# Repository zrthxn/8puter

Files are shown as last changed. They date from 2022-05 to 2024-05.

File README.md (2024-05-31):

# 8puter

This is a Homebrew 8-bit computer project, using mostly simple modern parts.
Based on the legendary MOS6502 processor, we are using the modern CMOS version made by WDC. Basically an exercise in computer architechture. I plan to get this manufactured into a PCB and assemble myself into a working computer. 

Please feel free to leave reviews/sanity checks from people who have done this sort of thing before, or know something about this, in the [issues](/issues).  

## Preview

Here is a picture of a 3D model of the completed PCB.
<p align="center">
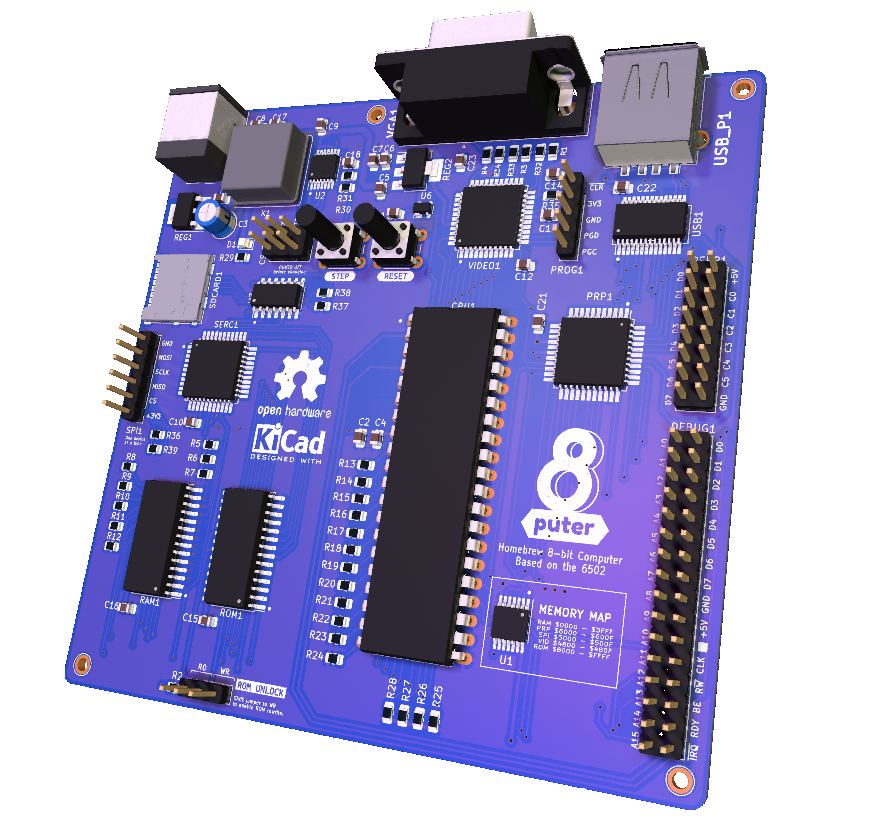
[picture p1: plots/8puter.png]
  
</p>

<p align="center" style="text-align: center; font-size: larger; font-weight: 600;">
// 
<a href="plots/8puter.pdf">Schematic</a> / 
<a href="plots/8puter.csv">Bill of Materials</a> 
//
</p>

## My Goals

The main thing I want to be able to do with this SBC is to program it with itself. This means having some way to input text from a keyboard and display it to some kind of screen/output device, and I've chosen a VGA monitor for this. I'm not trying to keep this compatible with the ROMs/BIOSs or code of old but I want to be able to write my own, preferably on the machine itself. 
Also, I dont want to use discrete logic for everything since I have some experience with trying to make that work. I'm also not necessarily using all DIP chips because of lack space, and going SMD isnt that much of a problem.

To store programs on a sort of "disk", I thought I need to add some sort of serial interface which can talk to a microSD card, such that the computer can use it as storage. This is accomplished via SPI. 
The peripheral interface talks to a USB controller and *should* be able to use a USB keyboard as input device. This idea was taken from the schematic of the [SBC dev board that WDC sells](https://wdc65xx.com/Single-Board-Computers/w65c02sxb/).

The video signal is being generated by a microcontroller because I thought that's probably the easiest way to get it working without worrying about a lot of VGA signal timing. This MCU is fast enough to generate a 640x480 screen and has enough memory to store the framebuffer and its the only *cheat* I've used. Some more details are in my schematic

### Main Parts

**uProcessor:** W65C02S  
**ROM and RAM:** AT28C256 and AS6C62256, both 32K  
**VIA:** W65C22  
**USB I/f:** FT245RL  
**Video:** PIC32MX270 uController

## Manufacturing

So after quite a while, I have finally got this PCB manufactured and it came out better than I had imagined.
I was having trouble finding a local PCB maker who had the right capabilities and would manufacture this board at a small scale. 
Then I found Robu.in and their manufacturing service. I'm not sure if they've been doing this for a while but I never knew about them.

The board files are ready to send to a manufacturer of your choice as they are. You can find the gerbers in a ZIP and just fire them off. 
I recommend Robu.in if you're in India. Otherwise I'd recommend PCBWay.com



See the [Releases](https://github.com/zrthxn/8puter/releases) for updates.

## Resources

Some great resources I found for this project, including those from people who have done this sort of thing before.

- [Ben Eater's Excellent Videos](https://www.youtube.com/watch?v=LnzuMJLZRdU&list=PLowKtXNTBypFbtuVMUVXNR0z1mu7dp7eH)
- [George Foot's videos](https://www.youtube.com/watch?v=EC1Ous1zT5w&list=PLWKtKD_FaUF6IsFc1maERpOwWM2hrOM3b)
- [forum.6502.org](http://forum.6502.org/)
- [WDC's own SBC board schematic](https://wdc65xx.com/Single-Board-Computers/w65c02sxb/)
- [6052 Primer](http://wilsonminesco.com/6502primer) on how to get started building your own, especially the [address decode](http://wilsonminesco.com/6502primer/addr_decoding.html) section
- [6502.org: Homebuilt Projects](http://www.6502.org/homebuilt)
- [This guy's breadboard computer](https://www.youtube.com/watch?v=sdFXc0Rkpvc&list=PLdGm_pyUmoII9D16mzw-XsJjHKi3f1kqT) which is based on the (later) 65816 processor, but has some great ideas.

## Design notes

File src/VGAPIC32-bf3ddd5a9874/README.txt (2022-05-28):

Introduction
------------

The VGAPIC32 project provides software and circuit information to generate an
analogue VGA signal from a PIC32 microcontroller. More details can be found in
the following article:

http://blogs.fsfe.org/pboddie/?p=1712

See also the docs directory for original versions of the different explanatory
diagrams.

Contact, Copyright and Licence Information
------------------------------------------

The author can be contacted at the following e-mail address:

paul@boddie.org.uk

Copyright and licence information can be found in the docs directory - see
docs/COPYING.txt and docs/gpl-3.0.txt for more information.

Hardware Details
================

The pin usage of this solution is documented below.

PIC32MX270F256B-50I/SP Pin Assignments
--------------------------------------

MCLR#          1  \/  28
HSYNC/OC1/RA0  2      27
VSYNC/OC2/RA1  3      26 RB15
       D0/RB0  4      25 RB14
       D1/RB1  5      24 RB13
       D2/RB2  6      23
       D3/RB3  7      22 RB11/PGEC2
               8      21 RB10/PGEC3
          RA2  9      20
          RA3 10      19
       D4/RB4 11      18 RB9
              12      17 RB8
              13      16 RB7/D7
       D5/RB5 14      15

Note that RB6 is not available on pin 15 on this device.

Data Signal Routing
-------------------

For one bit of intensity, two bits per colour channel:

D7 -> 2200R -> I

I -> diode -> R
I -> diode -> G
I -> diode -> B

D6 (not connected)

D5 -> 470R -> R
D4 -> 1000R -> R
D3 -> 470R -> G
D2 -> 1000R -> G
D1 -> 470R -> B
D0 -> 1000R -> B

HSYNC -> HS
VSYNC -> VS

Output Socket Pinout
--------------------

  5 (GND)  4 (NC)   3 (B)    2 (G)    1 (R)

      10 (GND) 9 (NC)   8 (GND)  7 (GND)  6 (GND)

  15 (NC)  14 (VS)  13 (HS)  12 (NC)  11 (NC)

Output Cable Pinout
-------------------

      1 (R)    2 (G)    3 (B)    4 (NC)   5 (GND)

  6 (GND)  7 (GND)  8 (GND)  9 (NC)   10 (GND)

      11 (NC)  12 (NC)  13 (HS)  14 (VS)  15 (NC)

References
----------

https://en.wikipedia.org/wiki/VGA_connector

http://papilio.cc/index.php?n=Papilio.VGAWing

http://lucidscience.com/pro-vga%20video%20generator-2.aspx

https://sites.google.com/site/h2obsession/CBM/C128/rgbi-to-vga

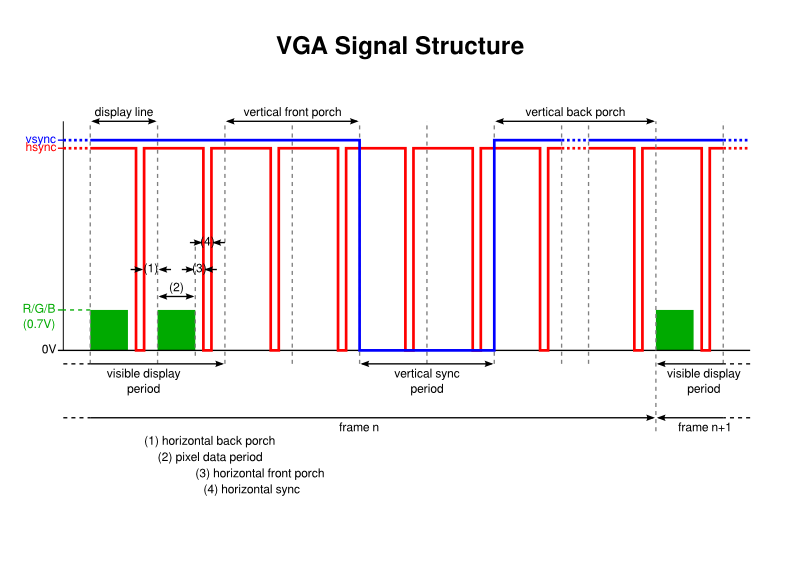
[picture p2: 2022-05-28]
src/VGAPIC32-bf3ddd5a9874/docs/vga_timing.png

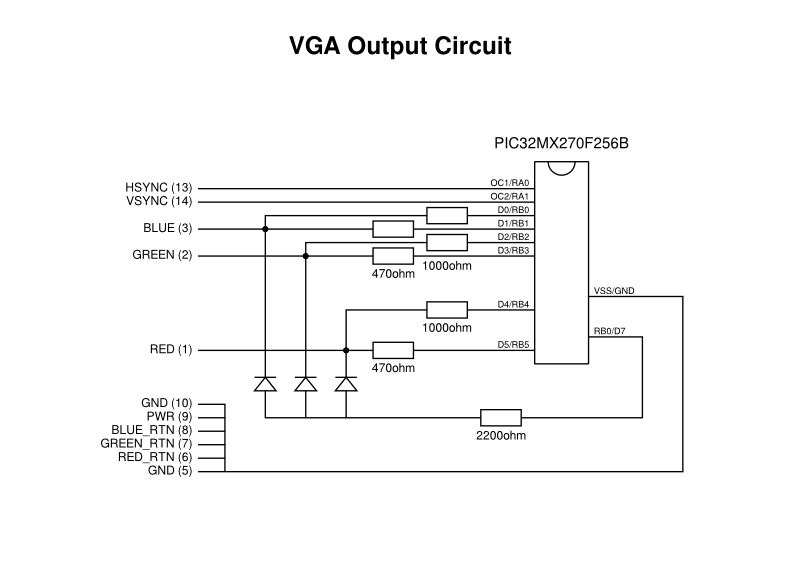
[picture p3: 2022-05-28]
src/VGAPIC32-bf3ddd5a9874/docs/vga_circuit.png

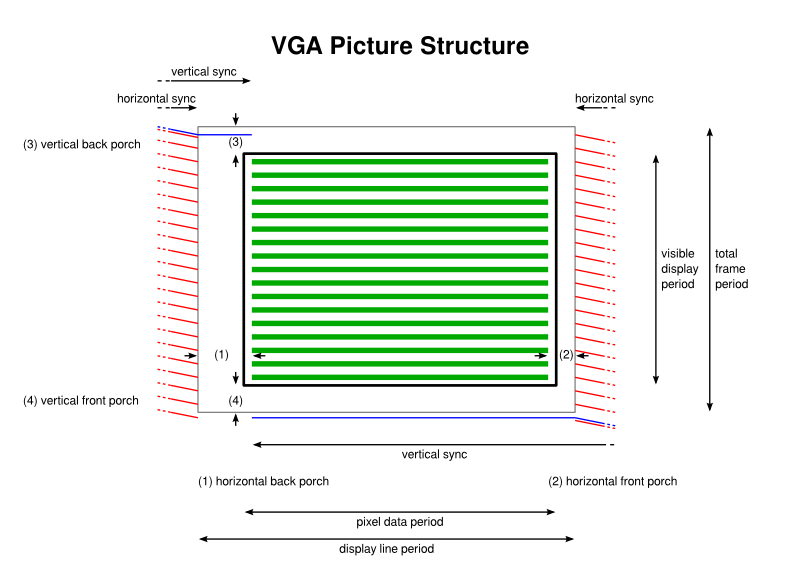
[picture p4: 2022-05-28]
src/VGAPIC32-bf3ddd5a9874/docs/vga_picture.png

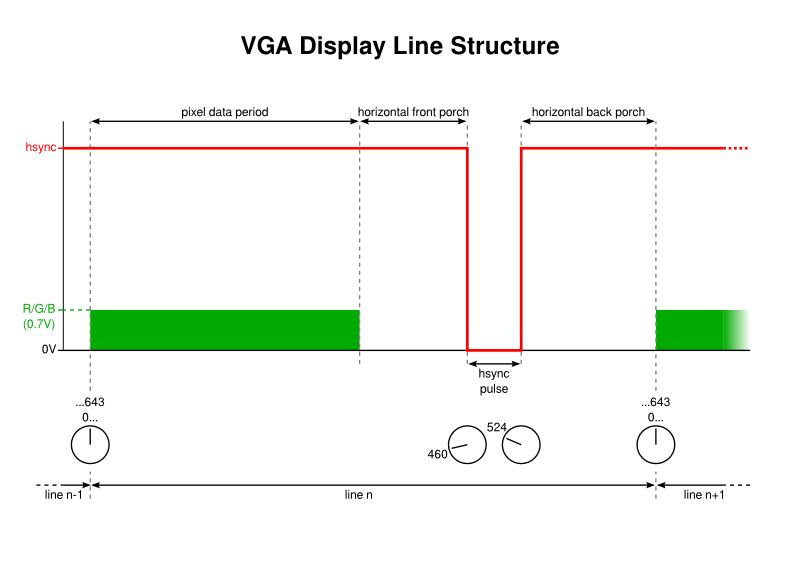
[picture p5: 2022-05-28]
src/VGAPIC32-bf3ddd5a9874/docs/vga_hsync.png

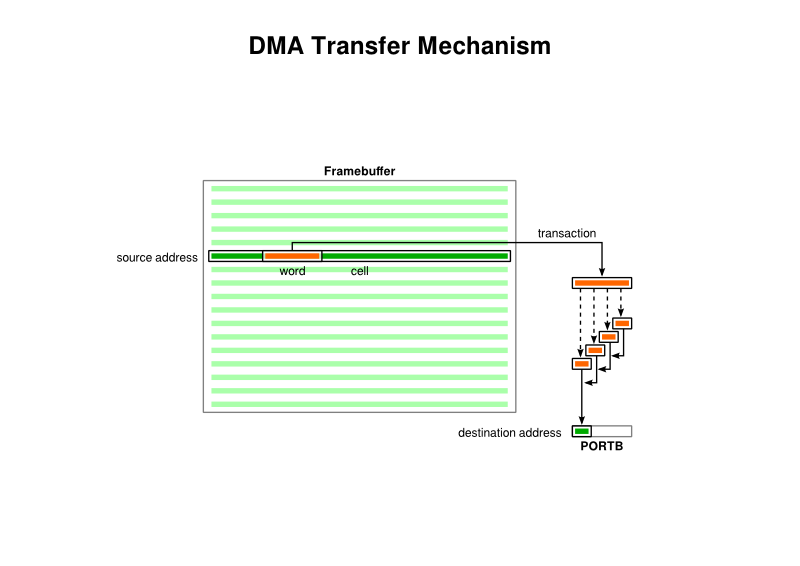
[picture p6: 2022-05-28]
src/VGAPIC32-bf3ddd5a9874/docs/dma_transfer.png

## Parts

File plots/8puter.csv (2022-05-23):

Id | Designator | Package | Quantity | Designation | Supplier and ref
1 | PERP1 | PinHeader_2x08_P2.54mm_Vertical | 1 | Conn_02x08_Odd_Even
2 | C15,C8,C9,C21,C16,C11,C22,C13,C14,C7,C10,C23 | C_0805_2012Metric | 12 | 100nF
3 | R30,R35 | R_0805_2012Metric | 2 | 10K
4 | R22,R28,R16,R13,R39,R11,R19,R2,R18,R6,R15,R4,R37,R27,R23,R24,R17,R36,R1,R9,R10,R29,R38,R25,R26,R20,R3,R14,R8,R21,R5,R7,R12 | R_0805_2012Metric | 33 | 1K
5 | SDCARD1 | microSD_HC_Molex_104031-0811 | 1 | Micro_SD_Card
6 | RESET_SW1,STEP_SW1 | SW_PUSH_6mm_H13mm | 2 | PUSHBTN
7 | ROM1 | SOIC-28W_7.5x17.9mm_P1.27mm | 1 | AT28HC256E-90SU
8 | U6 | SOT-143 | 1 | MAX811TEUS+T
9 | ROM_WRITE1 | PinHeader_1x03_P2.54mm_Vertical | 1 | Conn_01x03
10 | CPU1 | DIP-40_W15.24mm_LongPads | 1 | W65C02SxP
11 | R32,R34,R33 | R_0805_2012Metric | 3 | 470R
12 | C2,C17,C6,C18 | C_0805_2012Metric | 4 | 1uF
13 | REG2 | SOT-223-3_TabPin2 | 1 | NCP1117ST33T3G
14 | SERC1,PRP1 | PQFP-44_10x10mm_P0.8mm | 2 | W65C22SxQ
15 | PROG1 | PinHeader_1x05_P2.54mm_Vertical | 1 | Conn_01x05
16 | C3 | CP_Radial_D5.0mm_P2.50mm | 1 | 10uF 16V
17 | U1 | TSSOP-14_4.4x5mm_P0.65mm | 1 | 74AC00
18 | D1 | LED_0805_2012Metric | 1 | LED
19 | VGA1 | DSUB-15-HD_Female_Horizontal_P2.29x1.98mm_EdgePinOffset3.03mm_Housed_MountingHolesOffset4.94mm | 1 | DB15_Female_HighDensity
20 | SPI1 | PinHeader_1x06_P2.54mm_Vertical | 1 | Conn_01x06
21 | C4,C12,C1,C5 | C_0805_2012Metric | 4 | 10uF
22 | DEBUG1 | PinHeader_2x16_P2.54mm_Vertical | 1 | Conn_02x16_Odd_Even
23 | U3 | SOIC-14_3.9x8.7mm_P1.27mm | 1 | 74HC126
24 | USB1 | SSOP-28_5.3x10.2mm_P0.65mm | 1 | FT245RL
25 | RAM1 | SOIC-28W_7.5x17.9mm_P1.27mm | 1 | AS6C62256-55SINTR
26 | VIDEO1 | TQFP-44_10x10mm_P0.8mm | 1 | PIC32MX270F256D
27 | J1 | BarrelJack_CUI_PJ-063AH_Horizontal | 1 | PWR-DC
28 | REG1 | SOT-223-3_TabPin2 | 1 | NCP1117ST50T3G
29 | CS_SEL1 | PinHeader_2x03_P2.54mm_Vertical | 1 | Conn_02x03_Odd_Even
30 | U2 | TSSOP-14_4.4x5mm_P0.65mm | 1 | 74AHC74
31 | R31 | R_0805_2012Metric | 1 | 47K
32 | USB_P1 | USB_A_TE_292303-7_Horizontal | 1 | USB_A
33 | X1 | Oscillator_DIP-8 | 1 | ECS-2200BX-100

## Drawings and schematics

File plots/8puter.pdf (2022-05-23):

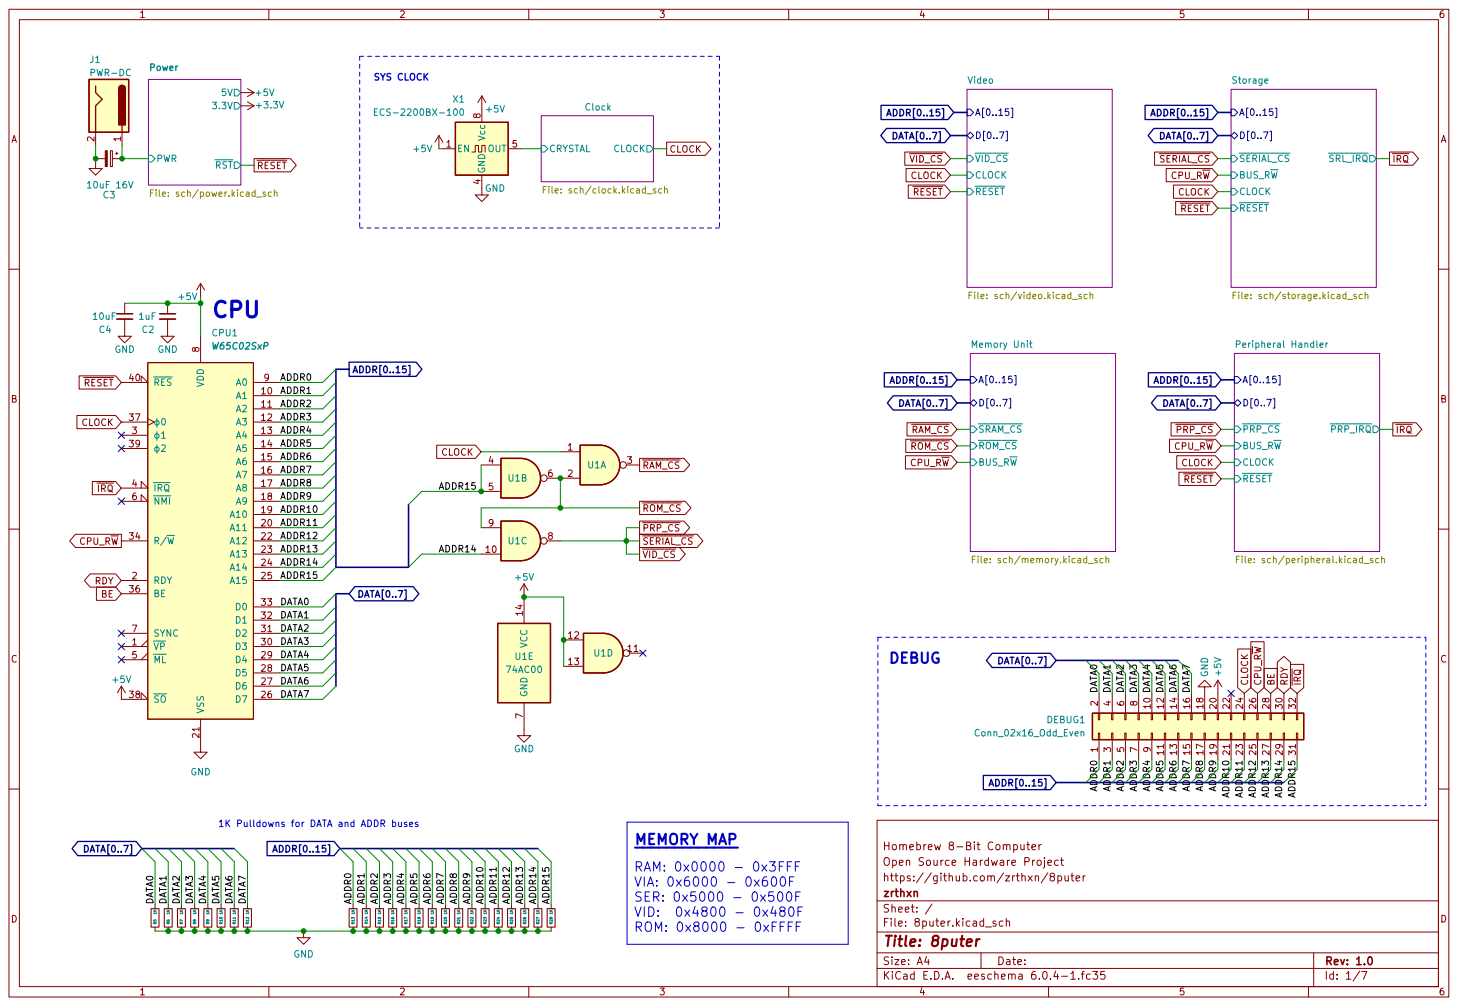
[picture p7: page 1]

+5V GND R17 1K +5V
File: sch/peripheral.kicad_sch PWR
1K Pulldowns for DATA and ADDR buses CPU

A[0..15] Video File: sch/video.kicad_sch A[0..15]
~{VID_CS} CLOCK DATA[0..7]

File: sch/storage.kicad_sch GNDVCC 14 GND

Homebrew 8-Bit Computer
Open Source Hardware Project
https://github.com/zrthxn/8puter
File: 8puter.kicad_sch Sheet: / zrthxn

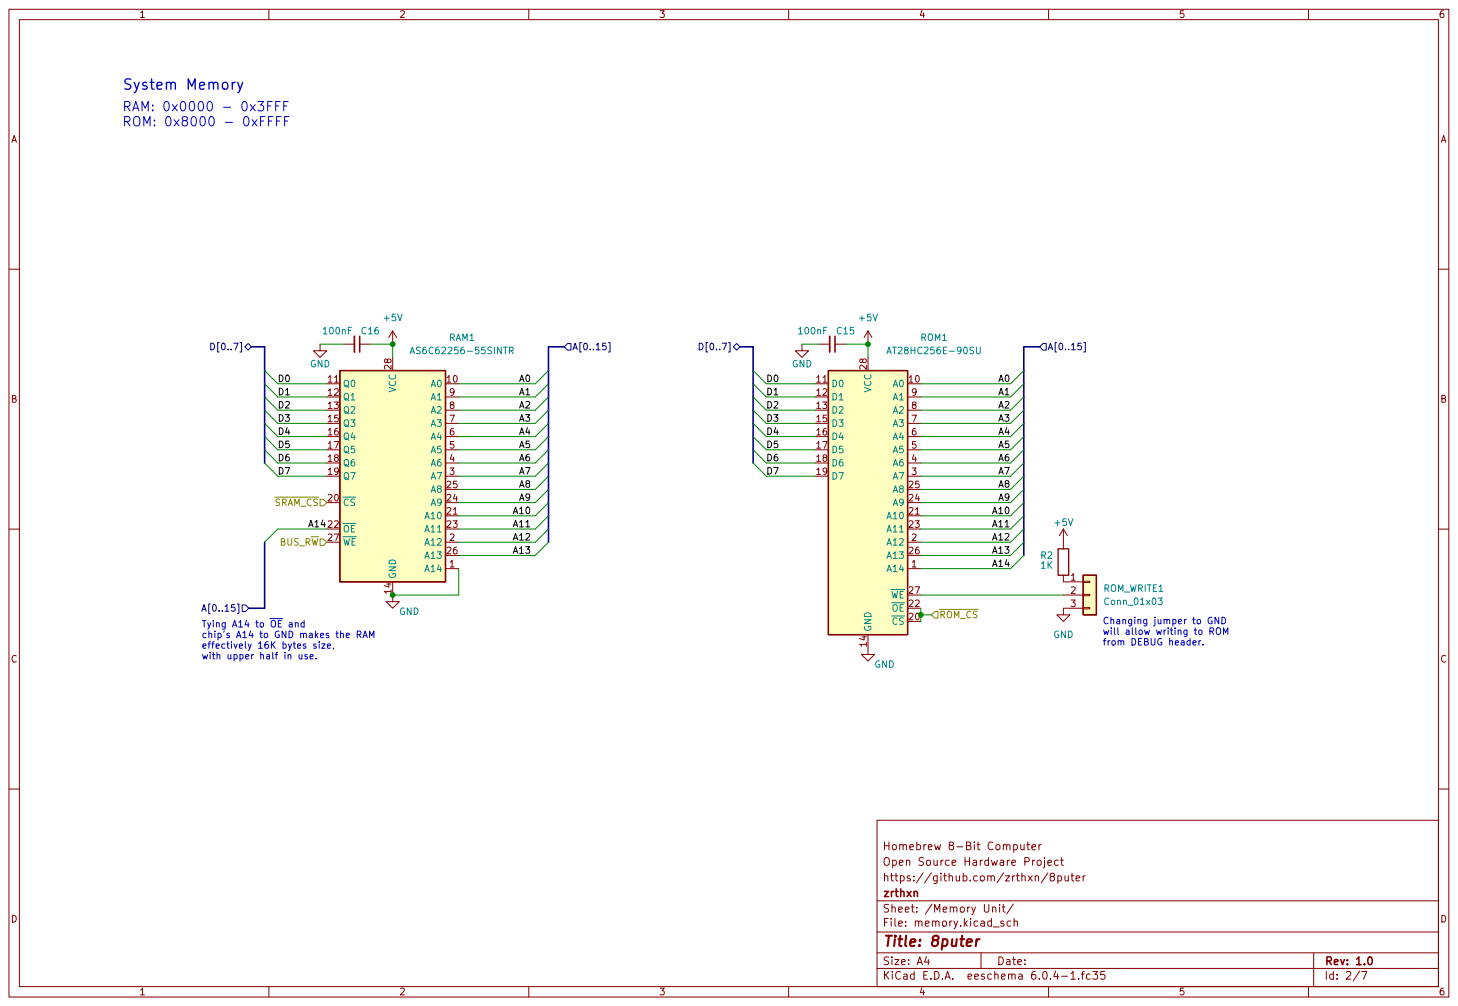
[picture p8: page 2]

Changing jumper to GND
will allow writing to ROM
from DEBUG header.

chip's A14 to GND makes the RAM
effectively 16K bytes size,
with upper half in use.

Homebrew 8-Bit Computer
Open Source Hardware Project
https://github.com/zrthxn/8puter
Sheet: /Memory Unit/ zrthxn

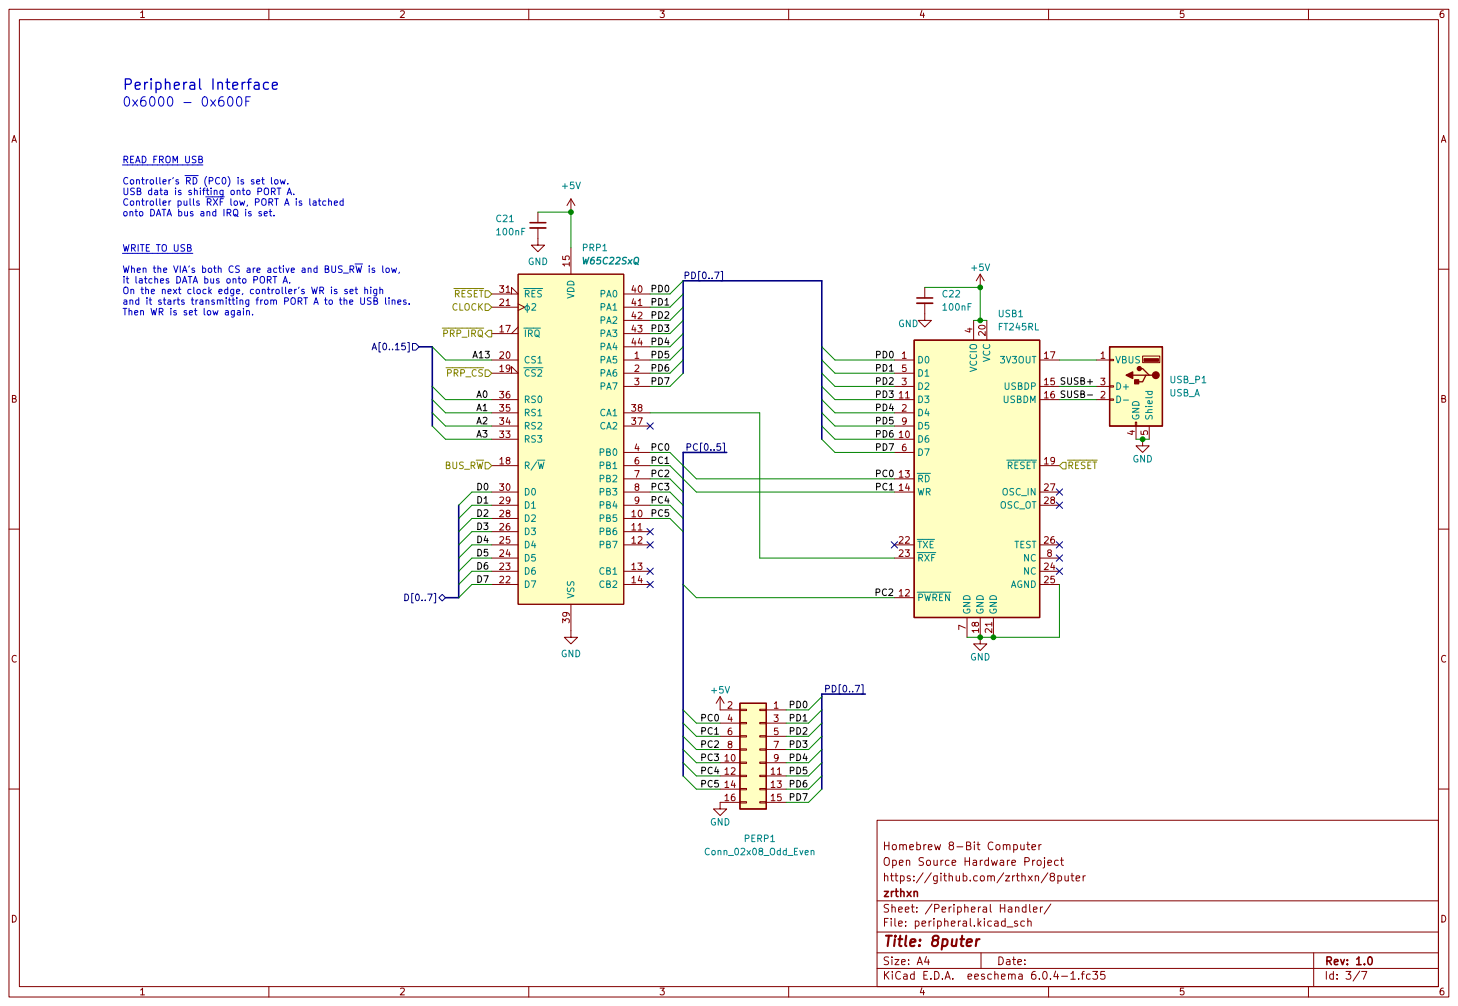
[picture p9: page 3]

Peripheral Interface WRITE TO USB
onto DATA bus and IRQ is set. 0x6000 - 0x600F

Controller's ~{RD} (PC0) is set low.
USB data is shifting onto PORT A.
Controller pulls ~{RXF} low, PORT A is latched

When the VIA's both CS are active and BUS_R~{W} is low,
it latches DATA bus onto PORT A. On the next clock edge, controller's WR is set high

and it starts transmitting from PORT A to the USB lines.
Then WR is set low again.

Homebrew 8-Bit Computer
Open Source Hardware Project
https://github.com/zrthxn/8puter
Sheet: /Peripheral Handler/ zrthxn

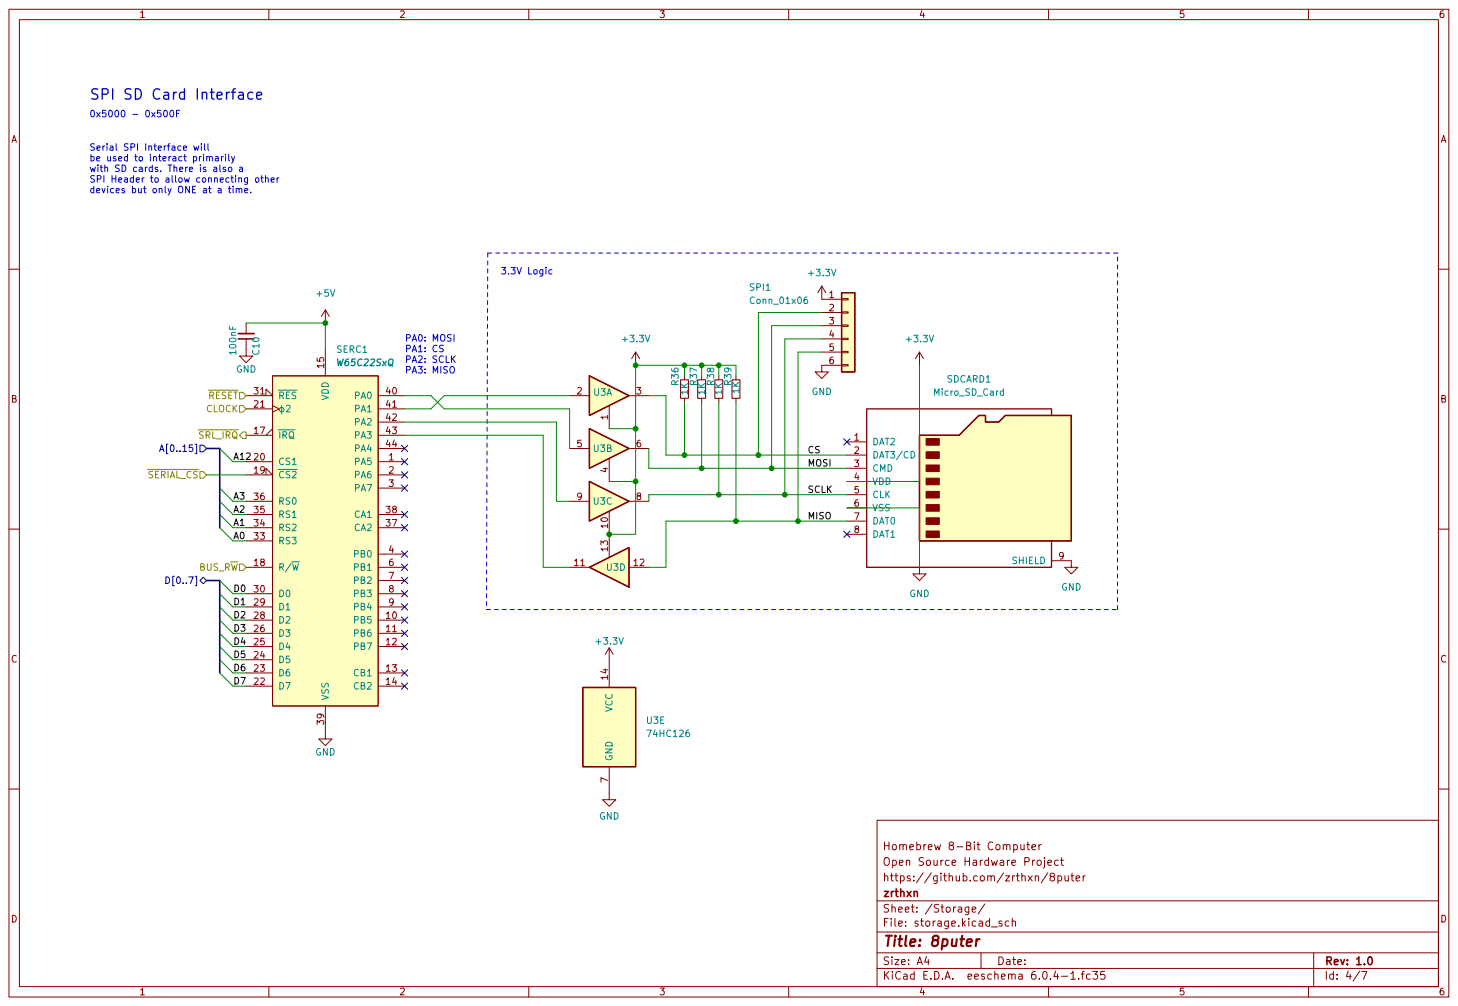
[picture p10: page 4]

SPI SD Card Interface

0x5000 - 0x500F Serial SPI Interface will be used to interact primarily with SD cards. There is also a SPI Header to allow connecting other

devices but only ONE at a time.

Open Source Hardware Project
https://github.com/zrthxn/8puter
Sheet: /Storage/ zrthxn

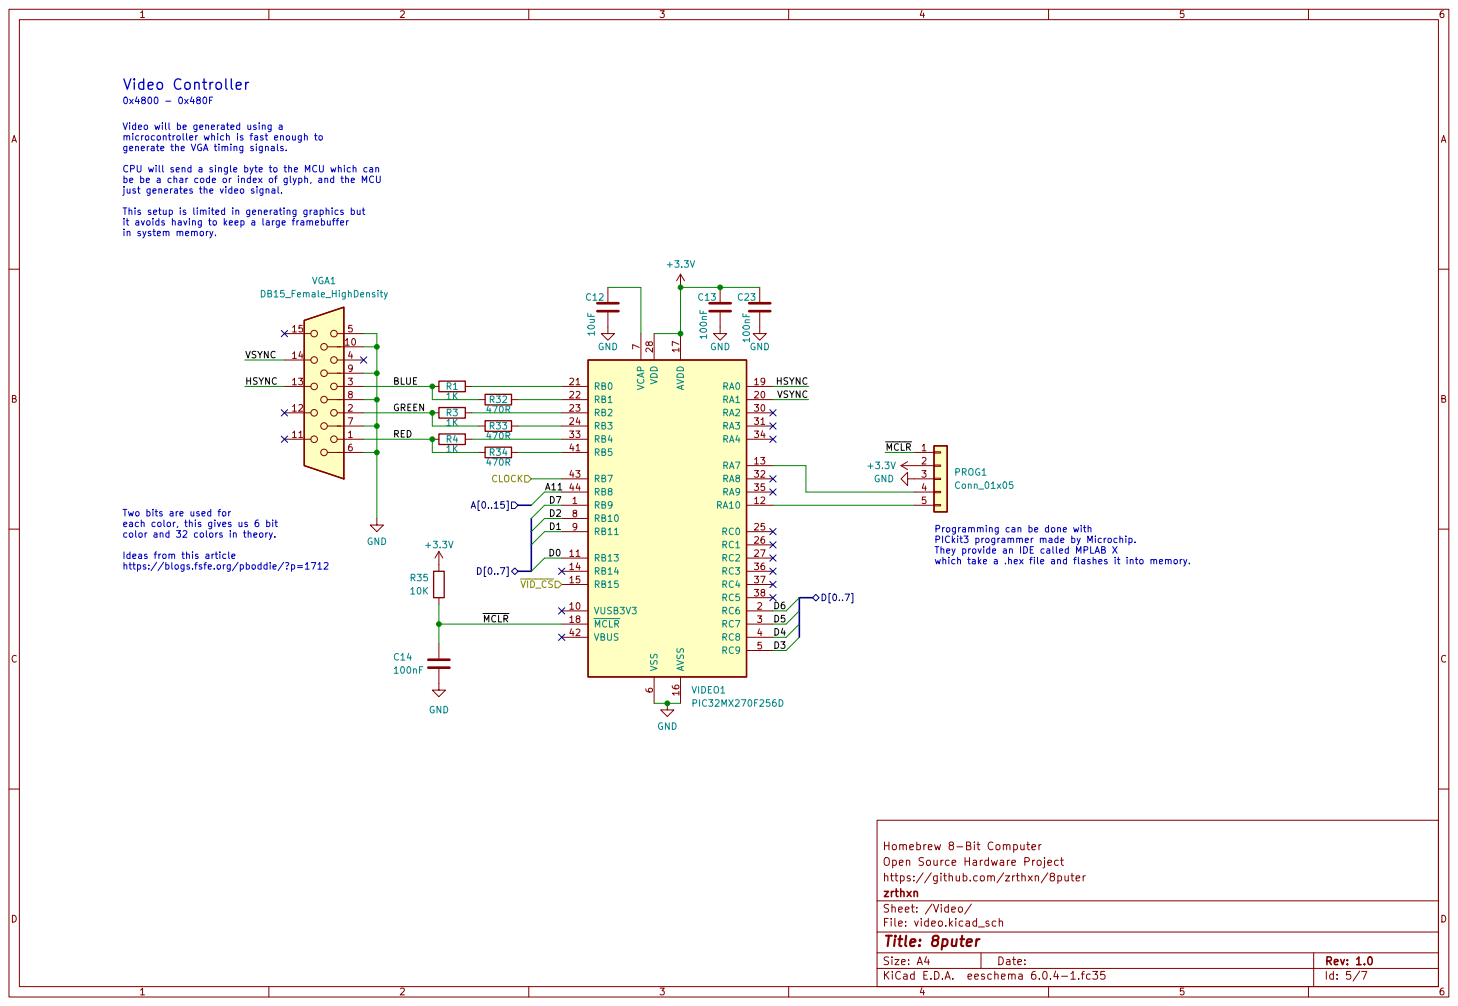
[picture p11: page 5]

Video Controller
0x4800 - 0x480F Video will be generated using a

microcontroller which is fast enough to
generate the VGA timing signals.

CPU will send a single byte to the MCU which can
be be a char code or index of glyph, and the MCU
just generates the video signal.

This setup is limited in generating graphics but
it avoids having to keep a large framebuffer
in system memory.

color and 32 colors in theory.

Programming can be done with
PICkit3 programmer made by Microchip.
They provide an IDE called MPLAB X
which take a .hex file and flashes it into memory.

Ideas from this article
https://blogs.fsfe.org/pboddie/?p=1712

Homebrew 8-Bit Computer
Open Source Hardware Project
https://github.com/zrthxn/8puter
File: video.kicad_sch Sheet: /Video/ zrthxn

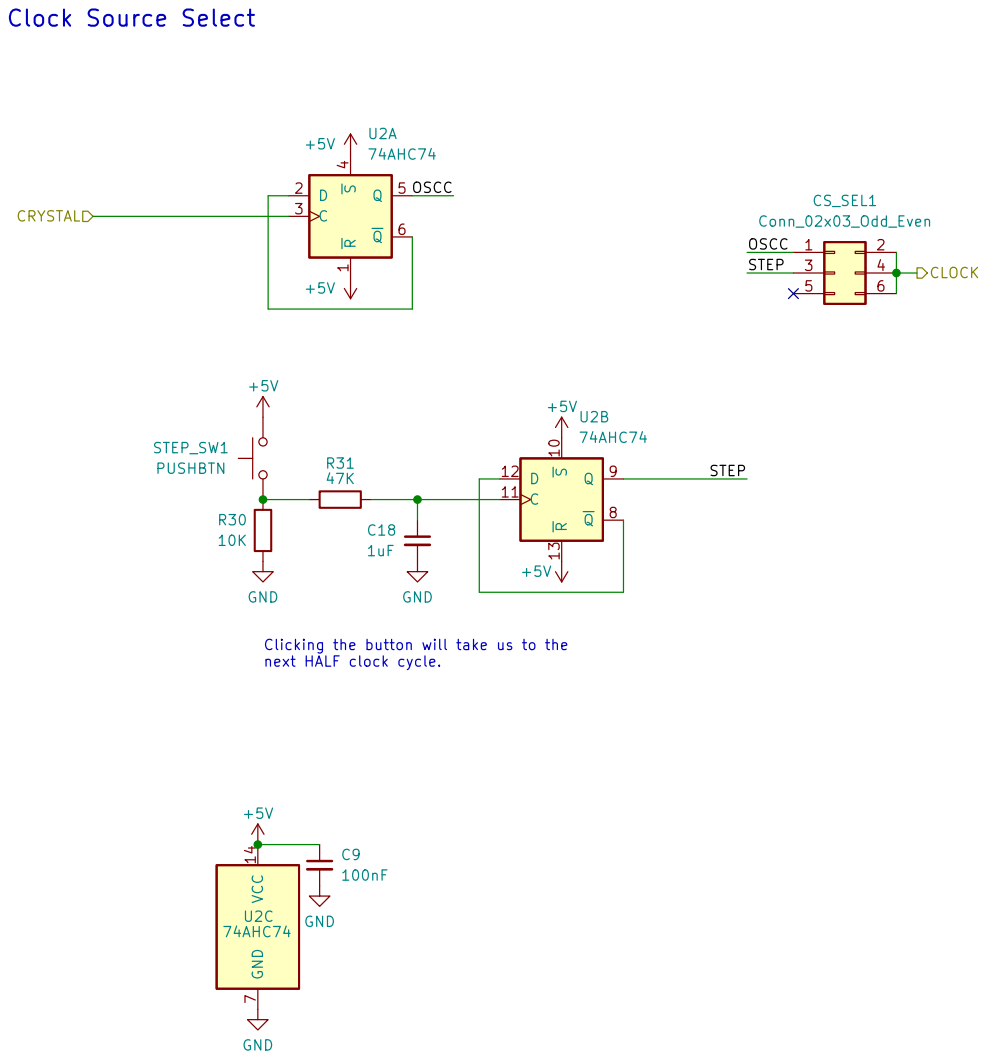
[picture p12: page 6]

Clicking the button will take us to the
next HALF clock cycle.

Homebrew 8-Bit Computer VCC 14 GND

Open Source Hardware Project
https://github.com/zrthxn/8puter
File: clock.kicad_sch Sheet: /Clock/ zrthxn

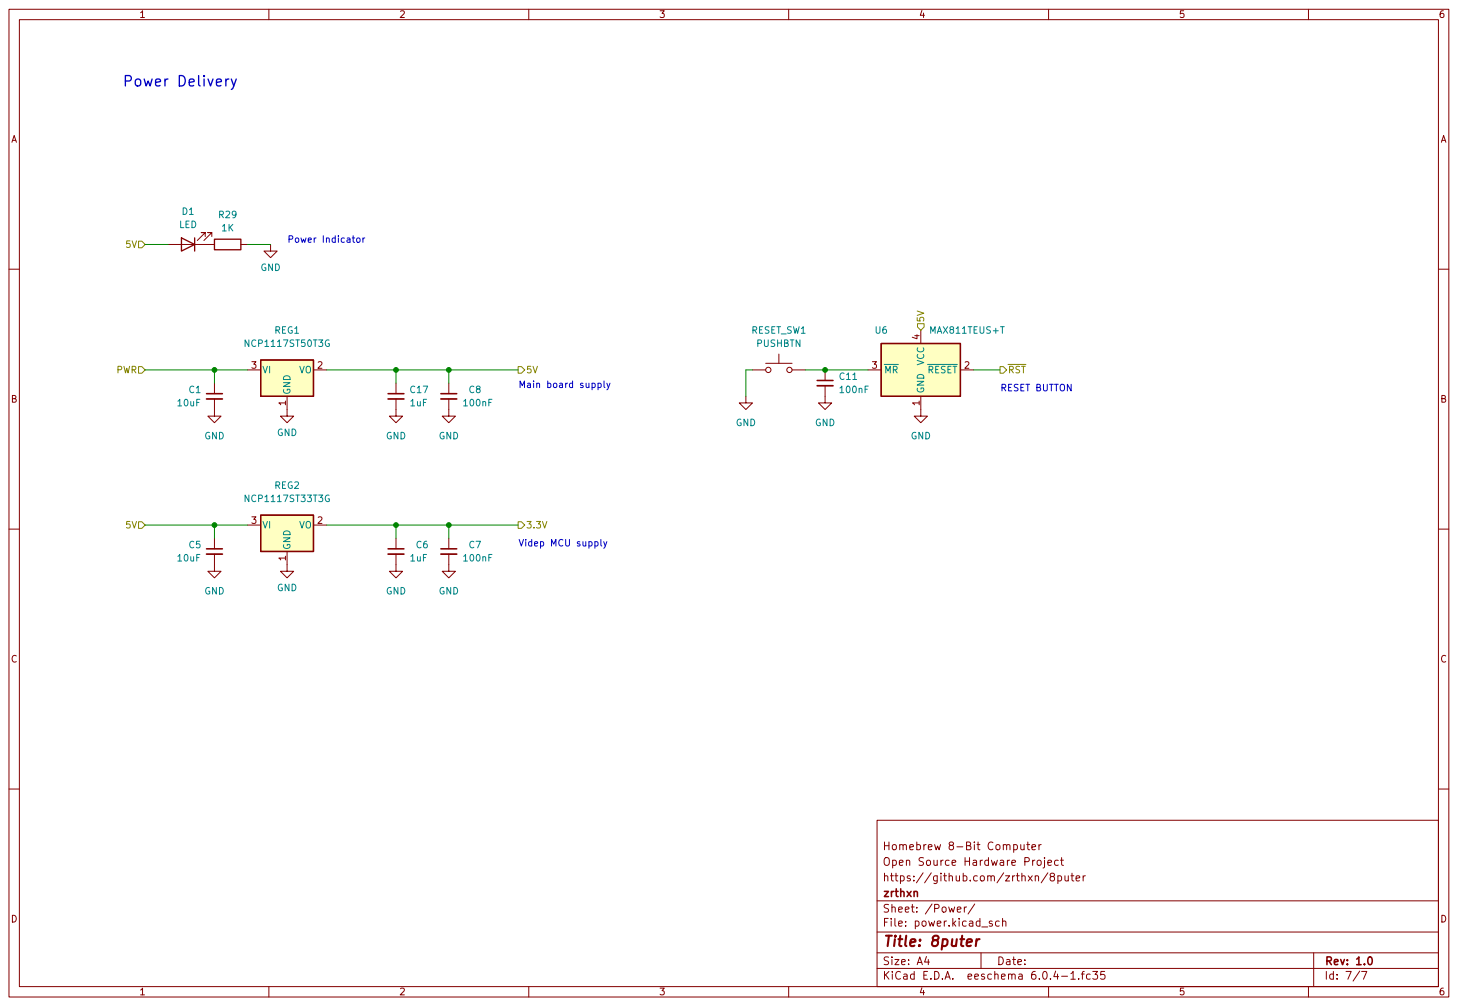
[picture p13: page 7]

Power Indicator Power Delivery

Homebrew 8-Bit Computer GND

Open Source Hardware Project
https://github.com/zrthxn/8puter
File: power.kicad_sch Sheet: /Power/ zrthxn

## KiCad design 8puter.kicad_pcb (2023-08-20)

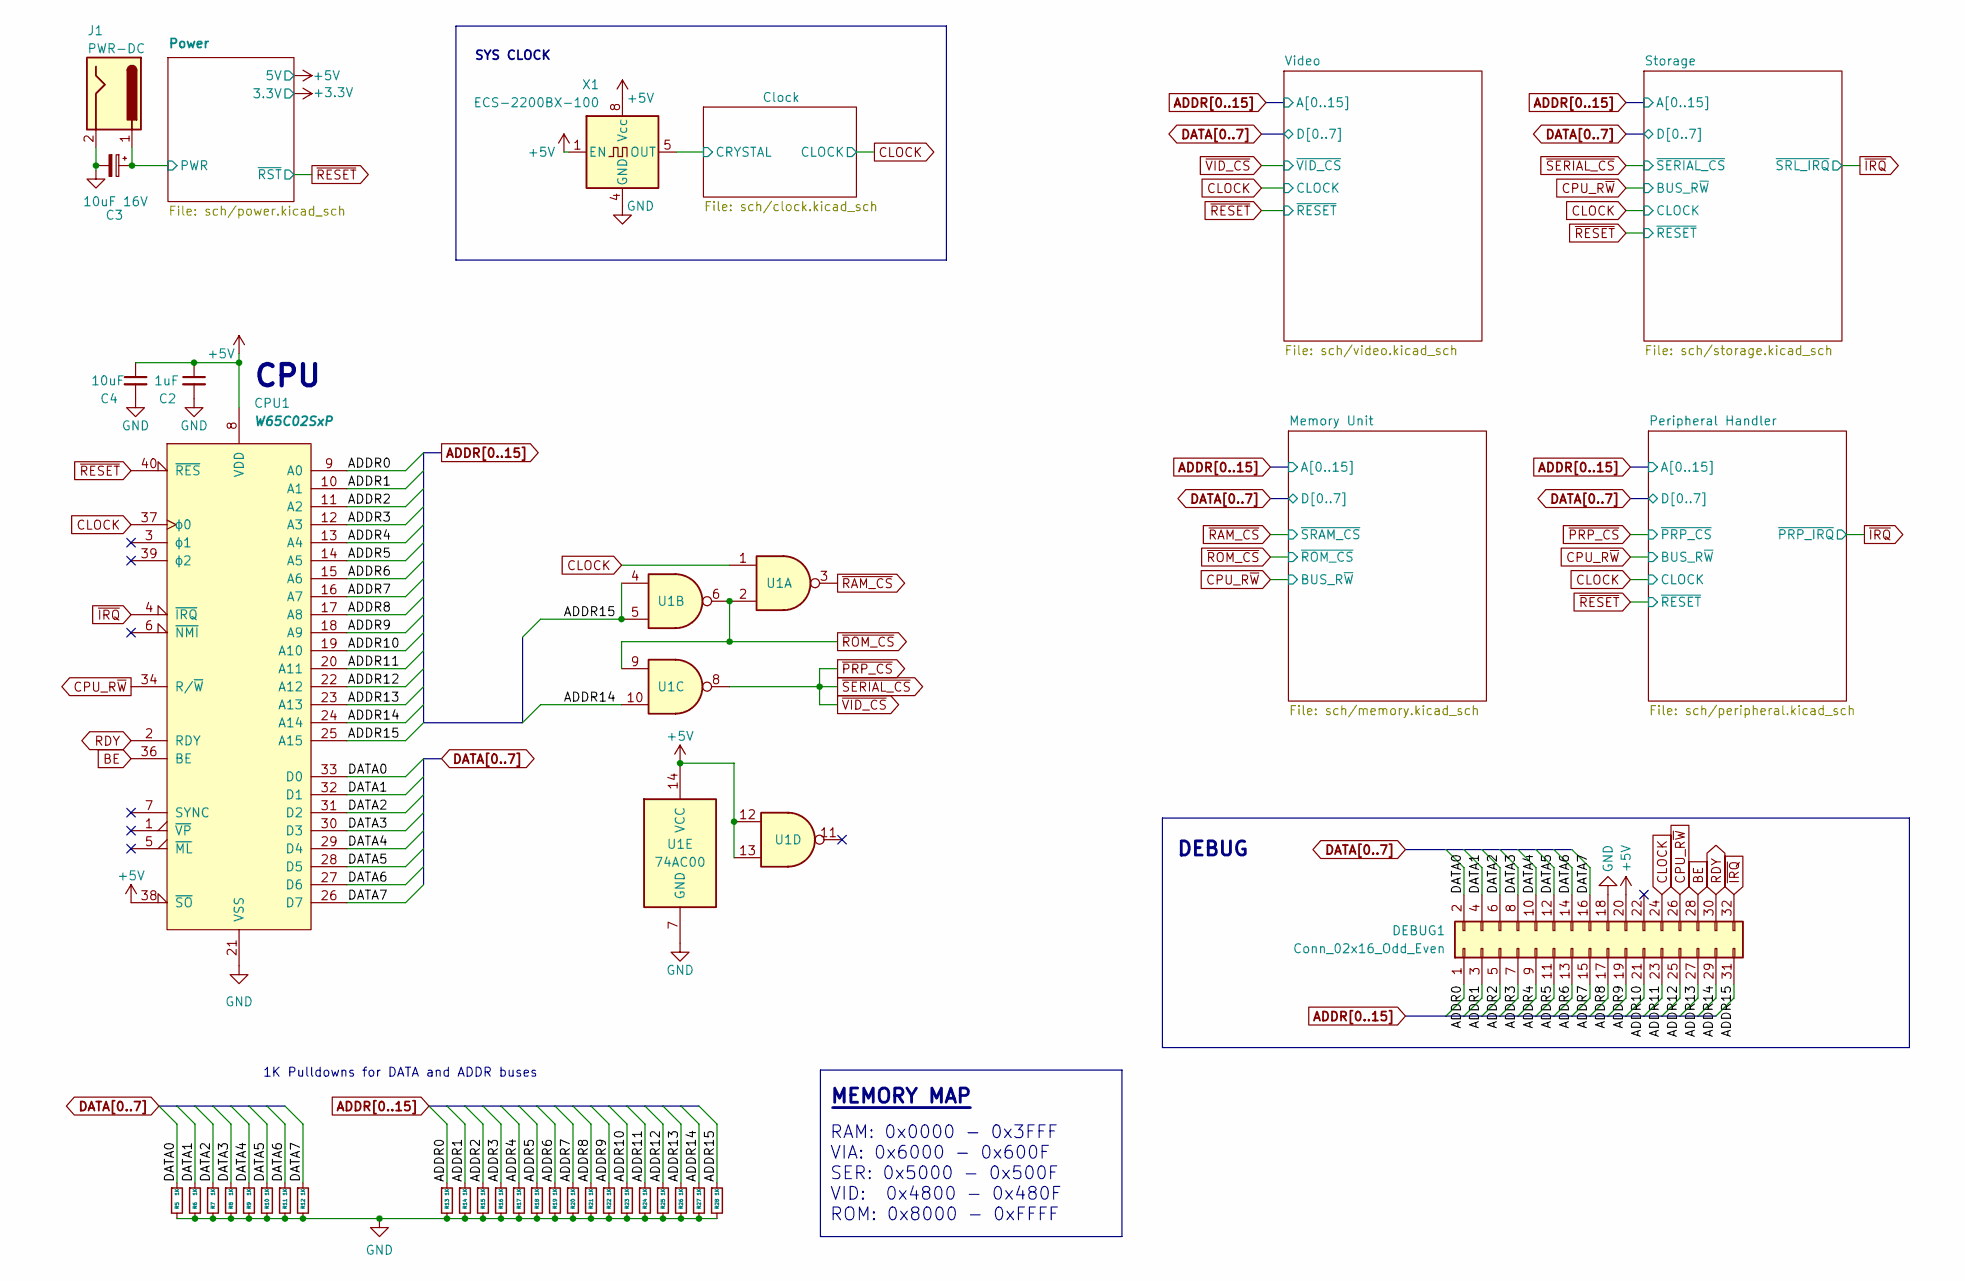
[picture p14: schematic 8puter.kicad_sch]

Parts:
C2: 1uF; C_0805_2012Metric
C3: 10uF 16V; CP_Radial_D5.0mm_P2.50mm
C4: 10uF; C_0805_2012Metric
CPU1: W65C02SxP; DIP-40_W15.24mm_LongPads
DEBUG1: Conn_02x16_Odd_Even; PinHeader_2x16_P2.54mm_Vertical
J1: PWR-DC; BarrelJack_CUI_PJ-063AH_Horizontal
R5, R6, R7, R8, R9, R10, R11, R12, R13, R14, R15, R16, R17, R18, R19, R20, R21, R22, R23, R24, R25, R26, R27, R28: 1K; R_0805_2012Metric
U1: 74AC00; TSSOP-14_4.4x5mm_P0.65mm
X1: ECS-2200BX-100; Oscillator_DIP-8

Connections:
+5V: C2.1, C4.1, CPU1.8 (VDD), CPU1.38 (~SO), DEBUG1.20, U1.12, U1.13, U1.14 (VCC), X1.1 (EN), X1.8 (Vcc); also elsewhere on the board
/Clock/CRYSTAL: X1.5 (OUT); also elsewhere on the board
/Power/PWR: C3.1, J1.1; also elsewhere on the board
ADDR0: CPU1.9 (A0), DEBUG1.1, R13.1; also elsewhere on the board
ADDR1: CPU1.10 (A1), DEBUG1.3, R14.1; also elsewhere on the board
ADDR2: CPU1.11 (A2), DEBUG1.5, R15.1; also elsewhere on the board
ADDR3: CPU1.12 (A3), DEBUG1.7, R16.1; also elsewhere on the board
ADDR4: CPU1.13 (A4), DEBUG1.9, R17.1; also elsewhere on the board
ADDR5: CPU1.14 (A5), DEBUG1.11, R18.1; also elsewhere on the board
ADDR6: CPU1.15 (A6), DEBUG1.13, R19.1; also elsewhere on the board
ADDR7: CPU1.16 (A7), DEBUG1.15, R20.1; also elsewhere on the board
ADDR8: CPU1.17 (A8), DEBUG1.17, R21.1; also elsewhere on the board
ADDR9: CPU1.18 (A9), DEBUG1.19, R22.1; also elsewhere on the board
ADDR10: CPU1.19 (A10), DEBUG1.21, R23.1; also elsewhere on the board
ADDR11: CPU1.20 (A11), DEBUG1.23, R24.1; also elsewhere on the board
ADDR12: CPU1.22 (A12), DEBUG1.25, R25.1; also elsewhere on the board
ADDR13: CPU1.23 (A13), DEBUG1.27, R26.1; also elsewhere on the board
ADDR14: CPU1.24 (A14), DEBUG1.29, R27.1, U1.10; also elsewhere on the board
ADDR15: CPU1.25 (A15), DEBUG1.31, R28.1, U1.4, U1.5
BE: CPU1.36 (BE), DEBUG1.28
CLOCK: CPU1.37 (ϕ0), DEBUG1.24, U1.1; also elsewhere on the board
CPU_R~W: CPU1.34 (R/~W), DEBUG1.26; also elsewhere on the board
DATA0: CPU1.33 (D0), DEBUG1.2, R5.1; also elsewhere on the board
DATA1: CPU1.32 (D1), DEBUG1.4, R6.1; also elsewhere on the board
DATA2: CPU1.31 (D2), DEBUG1.6, R7.1; also elsewhere on the board
DATA3: CPU1.30 (D3), DEBUG1.8, R8.1; also elsewhere on the board
DATA4: CPU1.29 (D4), DEBUG1.10, R9.1; also elsewhere on the board
DATA5: CPU1.28 (D5), DEBUG1.12, R10.1; also elsewhere on the board
DATA6: CPU1.27 (D6), DEBUG1.14, R11.1; also elsewhere on the board
DATA7: CPU1.26 (D7), DEBUG1.16, R12.1; also elsewhere on the board
RDY: CPU1.2 (RDY), DEBUG1.30
~IRQ: CPU1.4 (~IRQ), DEBUG1.32; also elsewhere on the board
~PRP_CS: U1.8; also elsewhere on the board
~RAM_CS: U1.3; also elsewhere on the board
~RESET: CPU1.40 (~RES); also elsewhere on the board
~ROM_CS: U1.2, U1.6, U1.9; also elsewhere on the board

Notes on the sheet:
SYS CLOCK
DEBUG
RAM: 0x0000 - 0x3FFF VIA: 0x6000 - 0x600F SER: 0x5000 - 0x500F VID: 0x4800 - 0x480F ROM: 0x8000 - 0xFFFF
MEMORY MAP ~{ }
1K Pulldowns for DATA and ADDR buses
CPU

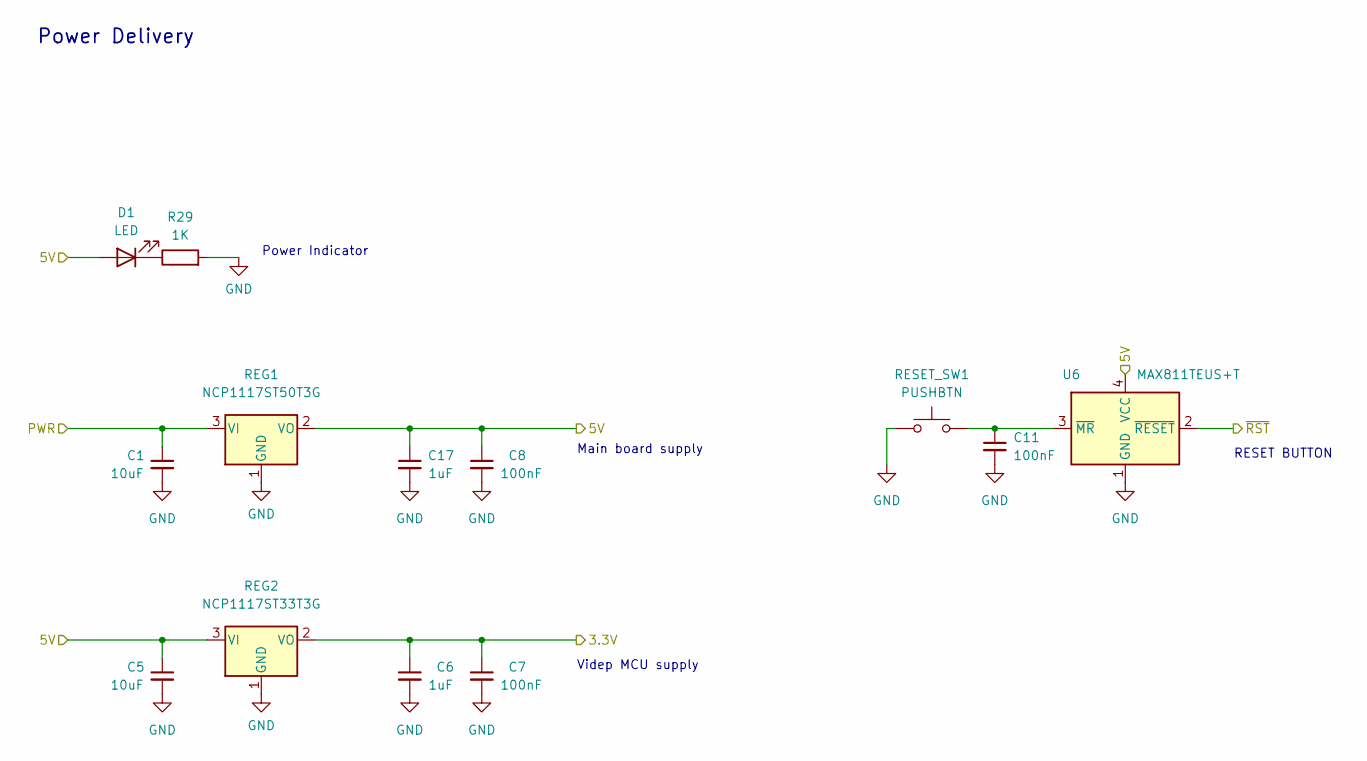
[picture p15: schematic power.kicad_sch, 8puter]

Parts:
C1, C5: 10uF; C_0805_2012Metric
C6, C17: 1uF; C_0805_2012Metric
C7, C8, C11: 100nF; C_0805_2012Metric
D1: LED; LED_0805_2012Metric
R29: 1K; R_0805_2012Metric
REG1: NCP1117ST50T3G; SOT-223-3_TabPin2
REG2: NCP1117ST33T3G; SOT-223-3_TabPin2
RESET_SW1: PUSHBTN; SW_PUSH_6mm_H13mm
U6: MAX811TEUS+T; SOT-143

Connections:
+3V3: C6.1, C7.1, REG2.2 (VO); also elsewhere on the board
+5V: C5.1, C8.1, C17.1, D1.2 (A), REG1.2 (VO), REG2.3 (VI), U6.4 (VCC); also elsewhere on the board
/Power/PWR: C1.1, REG1.3 (VI); also elsewhere on the board
unnamed: C11.1, RESET_SW1.2, U6.3 (~MR)
unnamed: D1.1 (K), R29.1
~RESET: U6.2 (~RESET); also elsewhere on the board

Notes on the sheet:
Power Delivery
RESET BUTTON
Videp MCU supply
Power Indicator
Main board supply

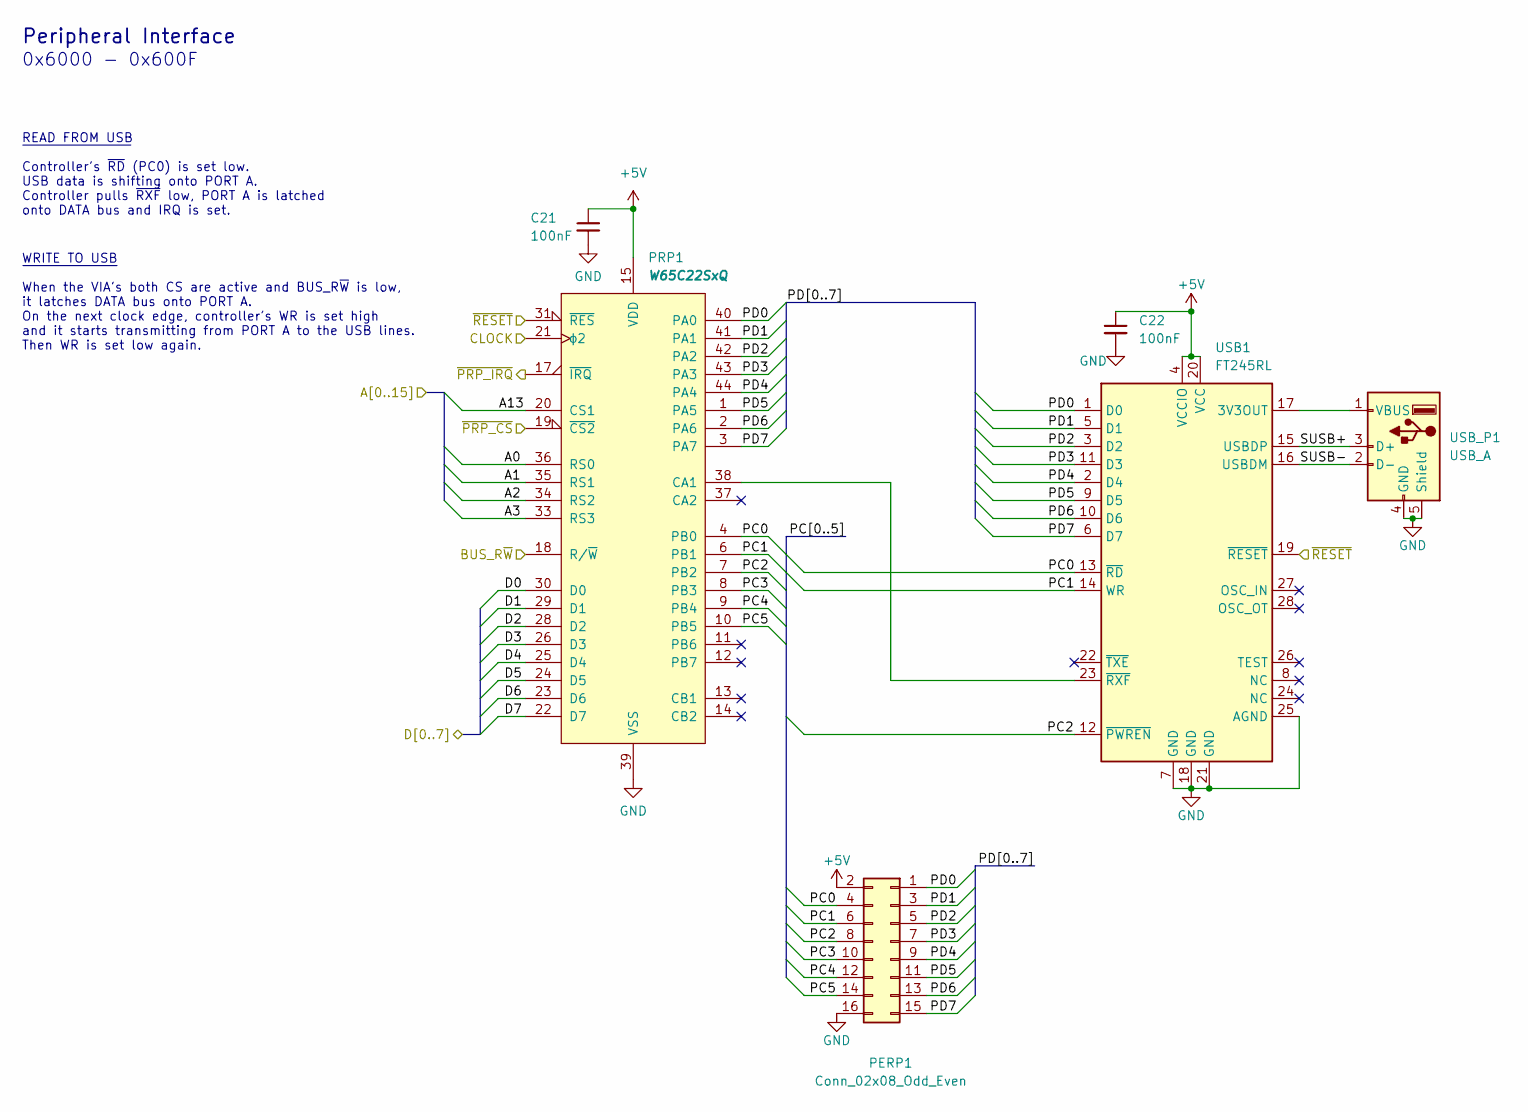
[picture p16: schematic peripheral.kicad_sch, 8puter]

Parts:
C21, C22: 100nF; C_0805_2012Metric
PERP1: Conn_02x08_Odd_Even; PinHeader_2x08_P2.54mm_Vertical
PRP1: W65C22SxQ; PQFP-44_10x10mm_P0.8mm
USB1: FT245RL; SSOP-28_5.3x10.2mm_P0.65mm
USB_P1: USB_A; USB_A_TE_292303-7_Horizontal

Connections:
+5V: C21.1, C22.1, PERP1.2, PRP1.15 (VDD), USB1.4 (VCCIO), USB1.20 (VCC); also elsewhere on the board
/Peripheral Handler/PC0: PERP1.4, PRP1.4 (PB0), USB1.13 (~RD)
/Peripheral Handler/PC1: PERP1.6, PRP1.6 (PB1), USB1.14 (WR)
/Peripheral Handler/PC2: PERP1.8, PRP1.7 (PB2), USB1.12 (~PWREN)
/Peripheral Handler/PC3: PERP1.10, PRP1.8 (PB3)
/Peripheral Handler/PC4: PERP1.12, PRP1.9 (PB4)
/Peripheral Handler/PC5: PERP1.14, PRP1.10 (PB5)
/Peripheral Handler/PD0: PERP1.1, PRP1.40 (PA0), USB1.1 (D0)
/Peripheral Handler/PD1: PERP1.3, PRP1.41 (PA1), USB1.5 (D1)
/Peripheral Handler/PD2: PERP1.5, PRP1.42 (PA2), USB1.3 (D2)
/Peripheral Handler/PD3: PERP1.7, PRP1.43 (PA3), USB1.11 (D3)
/Peripheral Handler/PD4: PERP1.9, PRP1.44 (PA4), USB1.2 (D4)
/Peripheral Handler/PD5: PERP1.11, PRP1.1 (PA5), USB1.9 (D5)
/Peripheral Handler/PD6: PERP1.13, PRP1.2 (PA6), USB1.10 (D6)
/Peripheral Handler/PD7: PERP1.15, PRP1.3 (PA7), USB1.6 (D7)
/Peripheral Handler/SUSB+: USB1.15 (USBDP), USB_P1.3 (D+)
/Peripheral Handler/SUSB-: USB1.16 (USBDM), USB_P1.2 (D-)
ADDR0: PRP1.36 (RS0); also elsewhere on the board
ADDR1: PRP1.35 (RS1); also elsewhere on the board
ADDR2: PRP1.34 (RS2); also elsewhere on the board
ADDR3: PRP1.33 (RS3); also elsewhere on the board
ADDR13: PRP1.20 (CS1); also elsewhere on the board
CLOCK: PRP1.21 (ϕ2); also elsewhere on the board
CPU_R~W: PRP1.18 (R/~W); also elsewhere on the board
DATA0: PRP1.30 (D0); also elsewhere on the board
DATA1: PRP1.29 (D1); also elsewhere on the board
DATA2: PRP1.28 (D2); also elsewhere on the board
DATA3: PRP1.26 (D3); also elsewhere on the board
DATA4: PRP1.25 (D4); also elsewhere on the board
DATA5: PRP1.24 (D5); also elsewhere on the board
DATA6: PRP1.23 (D6); also elsewhere on the board
DATA7: PRP1.22 (D7); also elsewhere on the board
unnamed: PRP1.38 (CA1), USB1.23 (~RXF)
unnamed: USB1.17 (3V3OUT), USB_P1.1 (VBUS)
~IRQ: PRP1.17 (~IRQ); also elsewhere on the board
~PRP_CS: PRP1.19 (~CS2); also elsewhere on the board
~RESET: PRP1.31 (~RES), USB1.19 (~RESET); also elsewhere on the board

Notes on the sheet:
0x6000 - 0x600F
Peripheral Interface
WRITE TO USB ~{ } When the VIA's both CS are active and BUS_R~{W} is low, it latches DATA bus onto PORT A. On the next clock edge, controller's WR is set high and it starts transmitting from PORT A to the USB lines. Then WR is set low again.
READ FROM USB ~{ } Controller's ~{RD} (PC0) is set low. USB data is shifting onto PORT A. Controller pulls ~{RXF} low, PORT A is latched onto DATA bus and IRQ is set.

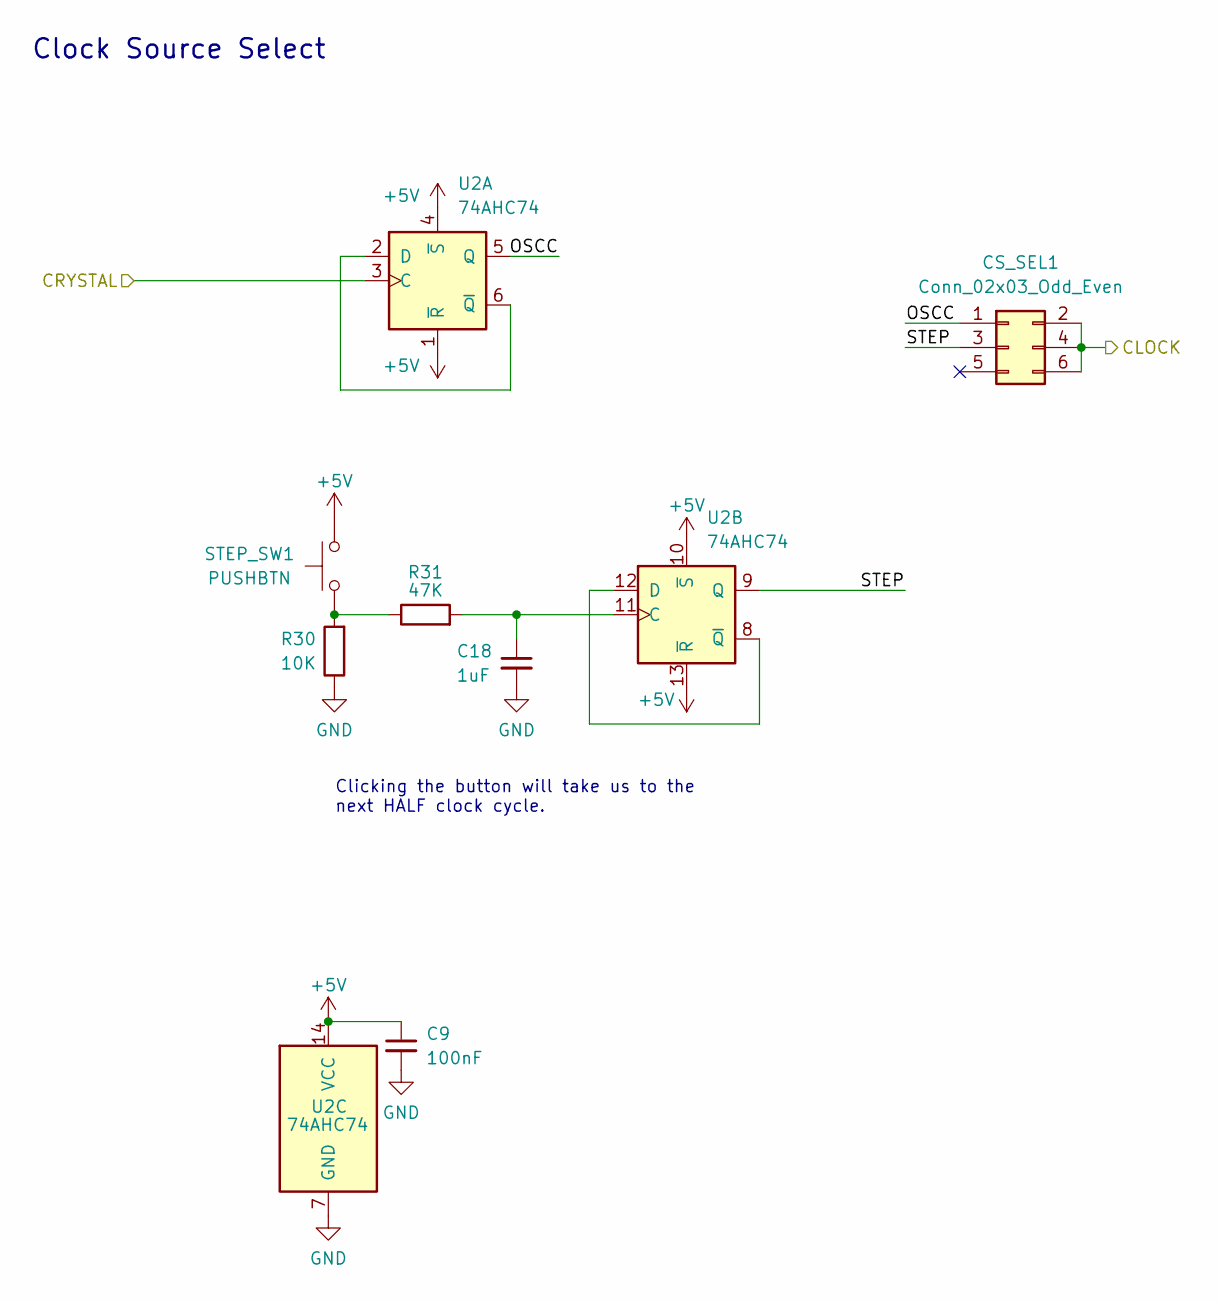
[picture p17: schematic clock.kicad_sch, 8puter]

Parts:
C9: 100nF; C_0805_2012Metric
C18: 1uF; C_0805_2012Metric
CS_SEL1: Conn_02x03_Odd_Even; PinHeader_2x03_P2.54mm_Vertical
R30: 10K; R_0805_2012Metric
R31: 47K; R_0805_2012Metric
STEP_SW1: PUSHBTN; SW_PUSH_6mm_H13mm
U2: 74AHC74; TSSOP-14_4.4x5mm_P0.65mm

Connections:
+5V: C9.1, STEP_SW1.2, U2.1 (~R), U2.4 (~S), U2.10 (~S), U2.13 (~R), U2.14 (VCC); also elsewhere on the board
/Clock/CRYSTAL: U2.3 (C); also elsewhere on the board
/Clock/OSCC: CS_SEL1.1, U2.5 (Q)
/Clock/STEP: CS_SEL1.3, U2.9 (Q)
CLOCK: CS_SEL1.2, CS_SEL1.4, CS_SEL1.6; also elsewhere on the board
unnamed: C18.1, R31.2, U2.11 (C)
unnamed: R30.2, R31.1, STEP_SW1.1
unnamed: U2.2 (D), U2.6 (~Q)
unnamed: U2.8 (~Q), U2.12 (D)

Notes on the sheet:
Clicking the button will take us to the next HALF clock cycle.
Clock Source Select

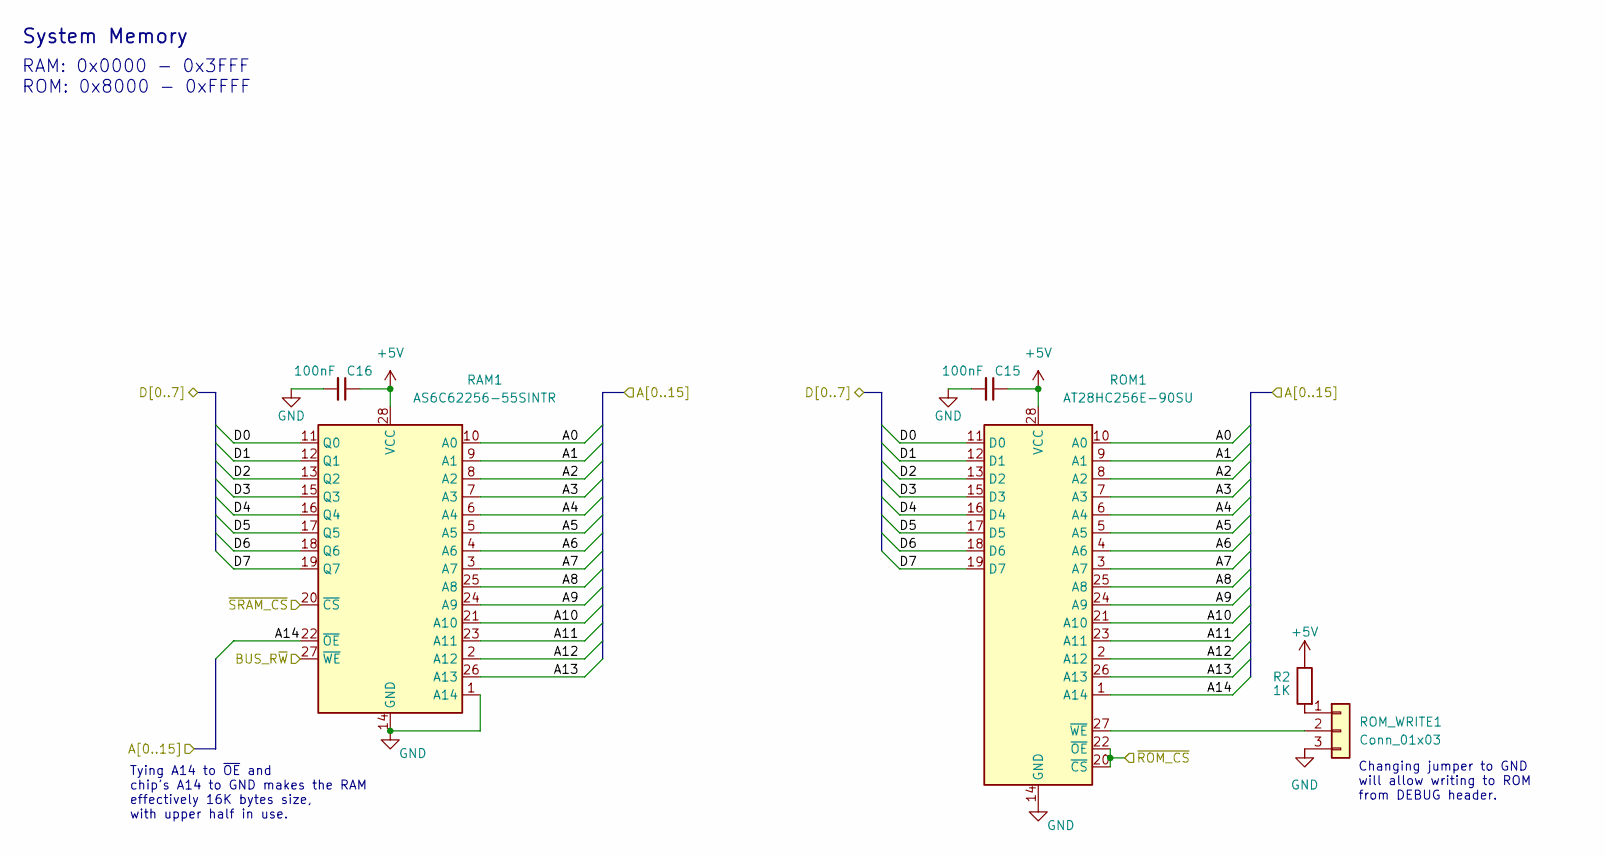
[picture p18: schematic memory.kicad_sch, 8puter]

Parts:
C15, C16: 100nF; C_0805_2012Metric
R2: 1K; R_0805_2012Metric
RAM1: AS6C62256-55SINTR; SOIC-28W_7.5x17.9mm_P1.27mm
ROM1: AT28HC256E-90SU; SOIC-28W_7.5x17.9mm_P1.27mm
ROM_WRITE1: Conn_01x03; PinHeader_1x03_P2.54mm_Vertical

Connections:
+5V: C15.1, C16.1, R2.1, RAM1.28 (VCC), ROM1.28 (VCC); also elsewhere on the board
ADDR0: RAM1.10 (A0), ROM1.10 (A0); also elsewhere on the board
ADDR1: RAM1.9 (A1), ROM1.9 (A1); also elsewhere on the board
ADDR2: RAM1.8 (A2), ROM1.8 (A2); also elsewhere on the board
ADDR3: RAM1.7 (A3), ROM1.7 (A3); also elsewhere on the board
ADDR4: RAM1.6 (A4), ROM1.6 (A4); also elsewhere on the board
ADDR5: RAM1.5 (A5), ROM1.5 (A5); also elsewhere on the board
ADDR6: RAM1.4 (A6), ROM1.4 (A6); also elsewhere on the board
ADDR7: RAM1.3 (A7), ROM1.3 (A7); also elsewhere on the board
ADDR8: RAM1.25 (A8), ROM1.25 (A8); also elsewhere on the board
ADDR9: RAM1.24 (A9), ROM1.24 (A9); also elsewhere on the board
ADDR10: RAM1.21 (A10), ROM1.21 (A10); also elsewhere on the board
ADDR11: RAM1.23 (A11), ROM1.23 (A11); also elsewhere on the board
ADDR12: RAM1.2 (A12), ROM1.2 (A12); also elsewhere on the board
ADDR13: RAM1.26 (A13), ROM1.26 (A13); also elsewhere on the board
ADDR14: RAM1.22 (~OE), ROM1.1 (A14); also elsewhere on the board
CPU_R~W: RAM1.27 (~WE); also elsewhere on the board
DATA0: RAM1.11 (Q0), ROM1.11 (D0); also elsewhere on the board
DATA1: RAM1.12 (Q1), ROM1.12 (D1); also elsewhere on the board
DATA2: RAM1.13 (Q2), ROM1.13 (D2); also elsewhere on the board
DATA3: RAM1.15 (Q3), ROM1.15 (D3); also elsewhere on the board
DATA4: RAM1.16 (Q4), ROM1.16 (D4); also elsewhere on the board
DATA5: RAM1.17 (Q5), ROM1.17 (D5); also elsewhere on the board
DATA6: RAM1.18 (Q6), ROM1.18 (D6); also elsewhere on the board
DATA7: RAM1.19 (Q7), ROM1.19 (D7); also elsewhere on the board
unnamed: R2.2, ROM_WRITE1.1
unnamed: ROM1.27 (~WE), ROM_WRITE1.2
~RAM_CS: RAM1.20 (~CS); also elsewhere on the board
~ROM_CS: ROM1.20 (~CS), ROM1.22 (~OE); also elsewhere on the board

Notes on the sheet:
RAM: 0x0000 - 0x3FFF ROM: 0x8000 - 0xFFFF
System Memory
Tying A14 to ~{OE} and chip's A14 to GND makes the RAM effectively 16K bytes size, with upper half in use.
Changing jumper to GND will allow writing to ROM from DEBUG header.

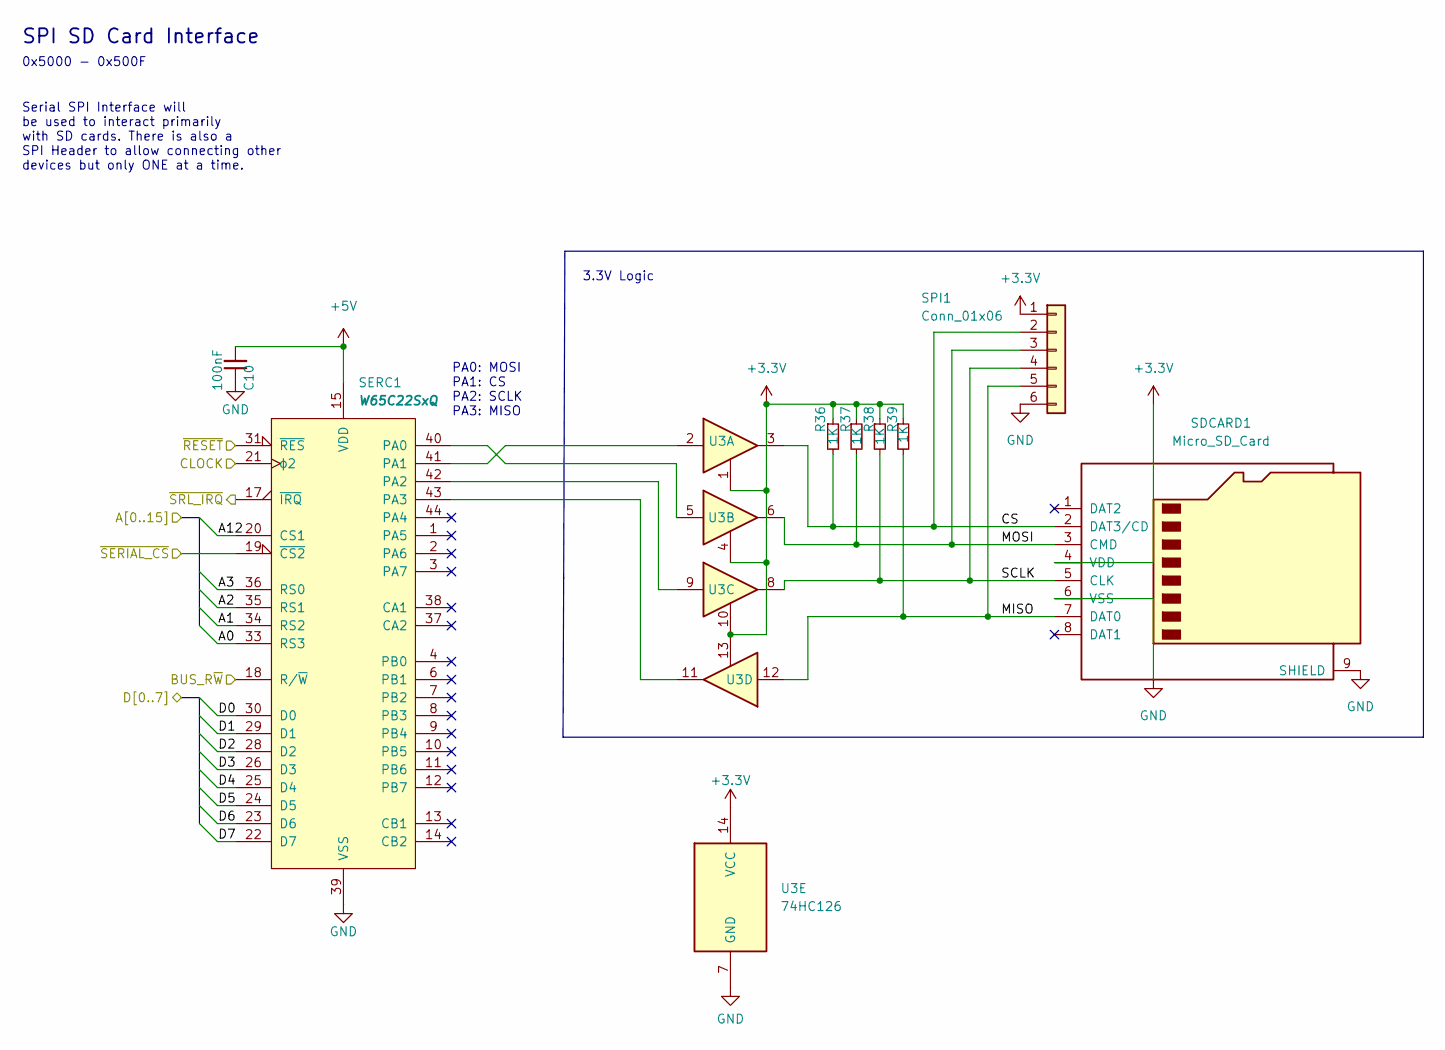
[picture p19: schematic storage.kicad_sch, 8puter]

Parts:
C10: 100nF; C_0805_2012Metric
R36, R37, R38, R39: 1K; R_0805_2012Metric
SDCARD1: Micro_SD_Card; microSD_HC_Molex_104031-0811
SERC1: W65C22SxQ; PQFP-44_10x10mm_P0.8mm
SPI1: Conn_01x06; PinHeader_1x06_P2.54mm_Vertical
U3: 74HC126; SOIC-14_3.9x8.7mm_P1.27mm

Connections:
+3V3: R36.1, R37.1, R38.1, R39.1, SDCARD1.4 (VDD), SPI1.1, U3.1, U3.4, U3.10, U3.13, U3.14 (VCC); also elsewhere on the board
+5V: C10.2, SERC1.15 (VDD); also elsewhere on the board
/Storage/CS: R36.2, SDCARD1.2 (DAT3/CD), SPI1.2, U3.3
/Storage/MISO: R39.2, SDCARD1.7 (DAT0), SPI1.5, U3.12
/Storage/MOSI: R37.2, SDCARD1.3 (CMD), SPI1.3, U3.6
/Storage/SCLK: R38.2, SDCARD1.5 (CLK), SPI1.4, U3.8
ADDR0: SERC1.33 (RS3); also elsewhere on the board
ADDR1: SERC1.34 (RS2); also elsewhere on the board
ADDR2: SERC1.35 (RS1); also elsewhere on the board
ADDR3: SERC1.36 (RS0); also elsewhere on the board
ADDR12: SERC1.20 (CS1); also elsewhere on the board
CLOCK: SERC1.21 (ϕ2); also elsewhere on the board
CPU_R~W: SERC1.18 (R/~W); also elsewhere on the board
DATA0: SERC1.30 (D0); also elsewhere on the board
DATA1: SERC1.29 (D1); also elsewhere on the board
DATA2: SERC1.28 (D2); also elsewhere on the board
DATA3: SERC1.26 (D3); also elsewhere on the board
DATA4: SERC1.25 (D4); also elsewhere on the board
DATA5: SERC1.24 (D5); also elsewhere on the board
DATA6: SERC1.23 (D6); also elsewhere on the board
DATA7: SERC1.22 (D7); also elsewhere on the board
unnamed: SERC1.40 (PA0), U3.5
unnamed: SERC1.41 (PA1), U3.2
unnamed: SERC1.42 (PA2), U3.9
unnamed: SERC1.43 (PA3), U3.11
~IRQ: SERC1.17 (~IRQ); also elsewhere on the board
~PRP_CS: SERC1.19 (~CS2); also elsewhere on the board
~RESET: SERC1.31 (~RES); also elsewhere on the board

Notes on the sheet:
SPI SD Card Interface
0x5000 - 0x500F
PA0: MOSI PA1: CS PA2: SCLK PA3: MISO
Serial SPI Interface will be used to interact primarily with SD cards. There is also a SPI Header to allow connecting other devices but only ONE at a time.
3.3V Logic

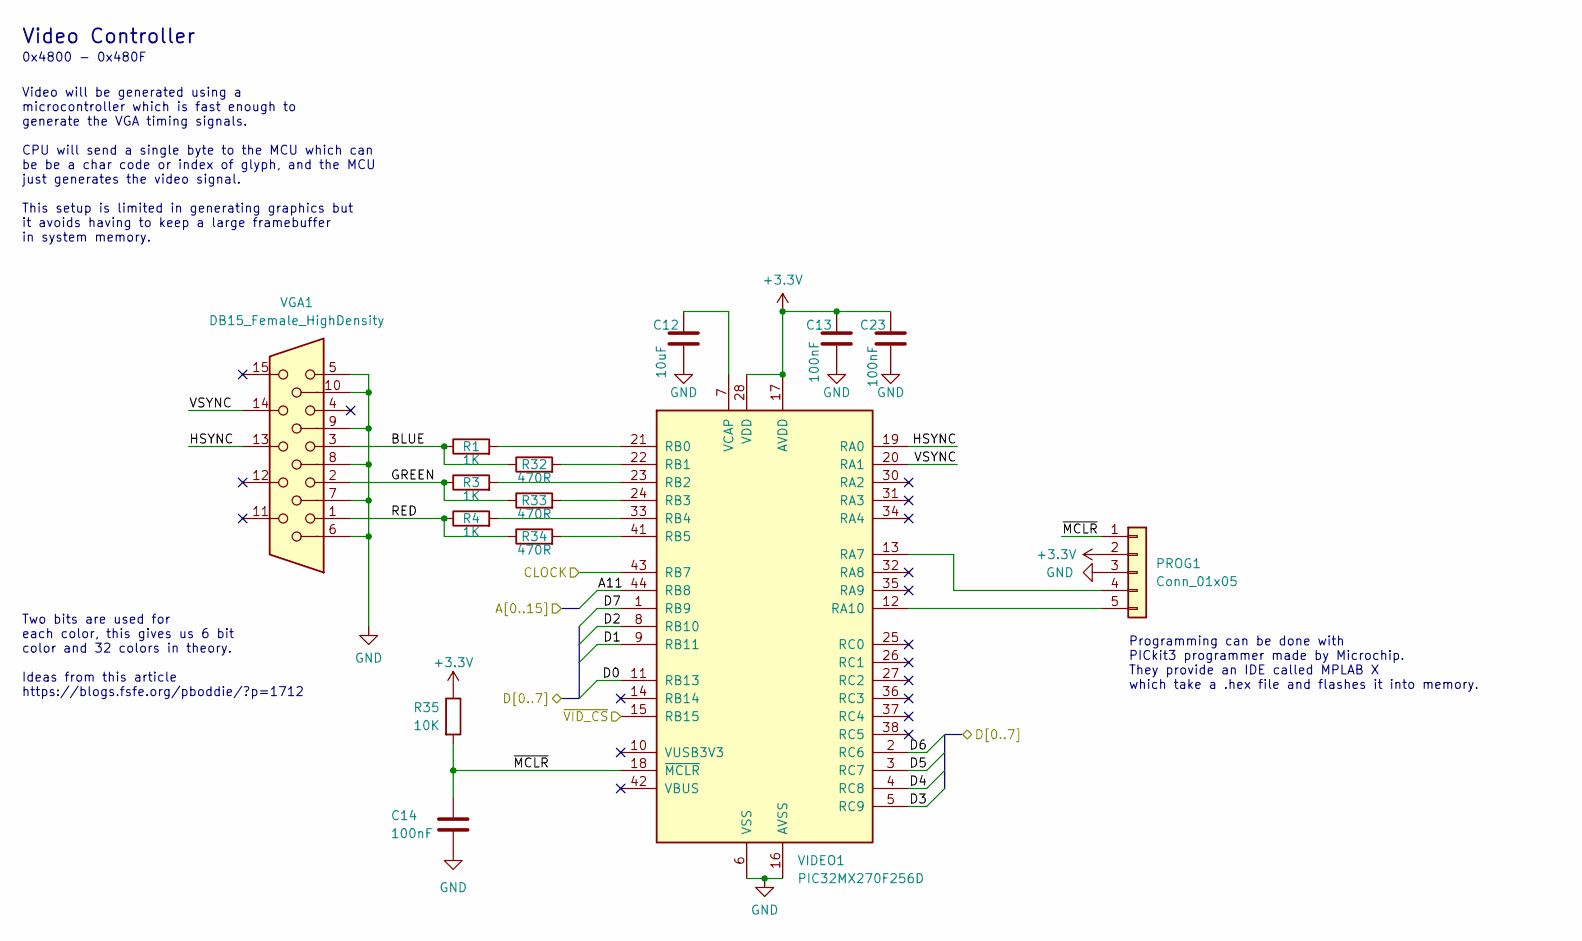
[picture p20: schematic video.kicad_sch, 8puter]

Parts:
C12: 10uF; C_0805_2012Metric
C13, C14, C23: 100nF; C_0805_2012Metric
PROG1: Conn_01x05; PinHeader_1x05_P2.54mm_Vertical
R1, R3, R4: 1K; R_0805_2012Metric
R32, R33, R34: 470R; R_0805_2012Metric
R35: 10K; R_0805_2012Metric
VGA1: DB15_Female_HighDensity; DSUB-15-HD_Female_Horizontal_P2.29x1.98mm_EdgePinOffset3.03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
VIDEO1: PIC32MX270F256D; TQFP-44_10x10mm_P0.8mm

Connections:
+3V3: C13.1, C23.1, PROG1.2, R35.1, VIDEO1.17 (AVDD), VIDEO1.28 (VDD), VIDEO1.40 (VDD); also elsewhere on the board
/Video/BLUE: R1.1, R32.1, VGA1.3
/Video/GREEN: R3.1, R33.1, VGA1.2
/Video/HSYNC: VGA1.13, VIDEO1.19 (RA0)
/Video/RED: R4.1, R34.1, VGA1.1
/Video/VSYNC: VGA1.14, VIDEO1.20 (RA1)
/Video/~MCLR: C14.1, PROG1.1, R35.2, VIDEO1.18 (~MCLR)
ADDR11: VIDEO1.44 (RB8); also elsewhere on the board
CLOCK: VIDEO1.43 (RB7); also elsewhere on the board
DATA0: VIDEO1.11 (RB13); also elsewhere on the board
DATA1: VIDEO1.9 (RB11); also elsewhere on the board
DATA2: VIDEO1.8 (RB10); also elsewhere on the board
DATA3: VIDEO1.5 (RC9); also elsewhere on the board
DATA4: VIDEO1.4 (RC8); also elsewhere on the board
DATA5: VIDEO1.3 (RC7); also elsewhere on the board
DATA6: VIDEO1.2 (RC6); also elsewhere on the board
DATA7: VIDEO1.1 (RB9); also elsewhere on the board
unnamed: C12.1, VIDEO1.7 (VCAP)
unnamed: PROG1.4, VIDEO1.13 (RA7)
unnamed: PROG1.5, VIDEO1.12 (RA10)
unnamed: R1.2, VIDEO1.21 (RB0)
unnamed: R3.2, VIDEO1.23 (RB2)
unnamed: R4.2, VIDEO1.33 (RB4)
unnamed: R32.2, VIDEO1.22 (RB1)
unnamed: R33.2, VIDEO1.24 (RB3)
unnamed: R34.2, VIDEO1.41 (RB5)
~PRP_CS: VIDEO1.15 (RB15); also elsewhere on the board

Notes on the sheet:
Video Controller
0x4800 - 0x480F
Two bits are used for each color, this gives us 6 bit color and 32 colors in theory. Ideas from this article https://blogs.fsfe.org/pboddie/?p=1712
Programming can be done with PICkit3 programmer made by Microchip. They provide an IDE called MPLAB X which take a .hex file and flashes it into memory.
Video will be generated using a microcontroller which is fast enough to generate the VGA timing signals. CPU will send a single byte to the MCU which can be be a char code or index of glyph, and the MCU just generates the video signal. This setup is limited in generating graphics but it avoids havi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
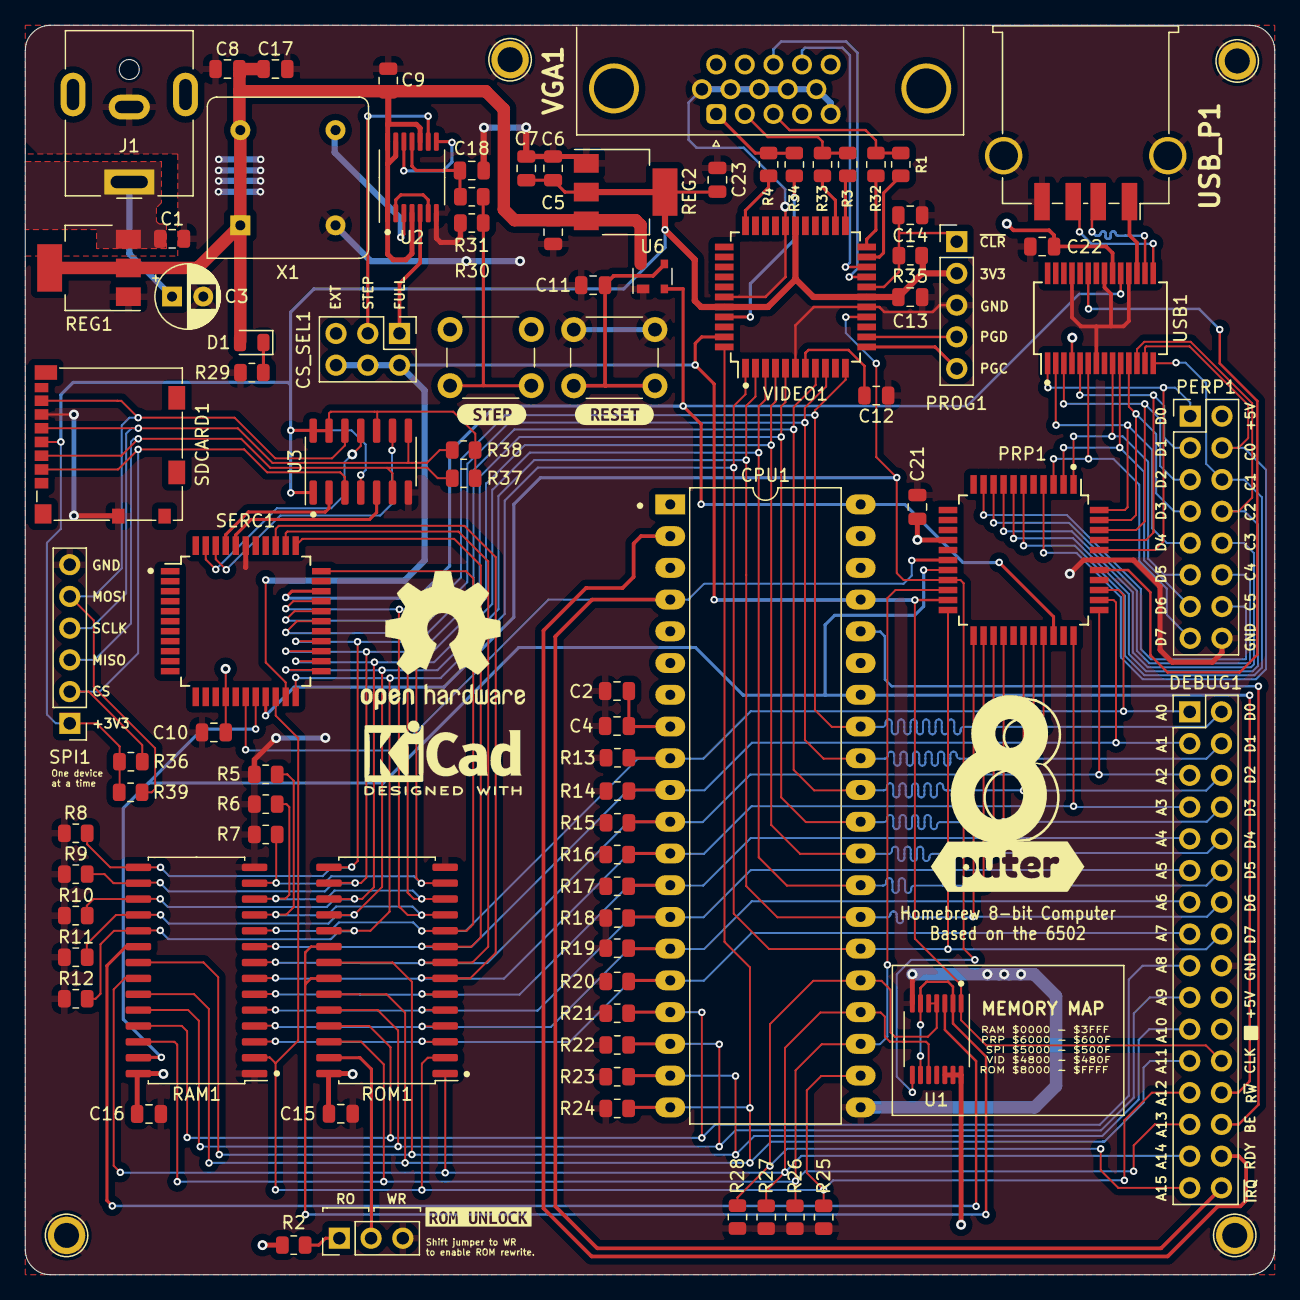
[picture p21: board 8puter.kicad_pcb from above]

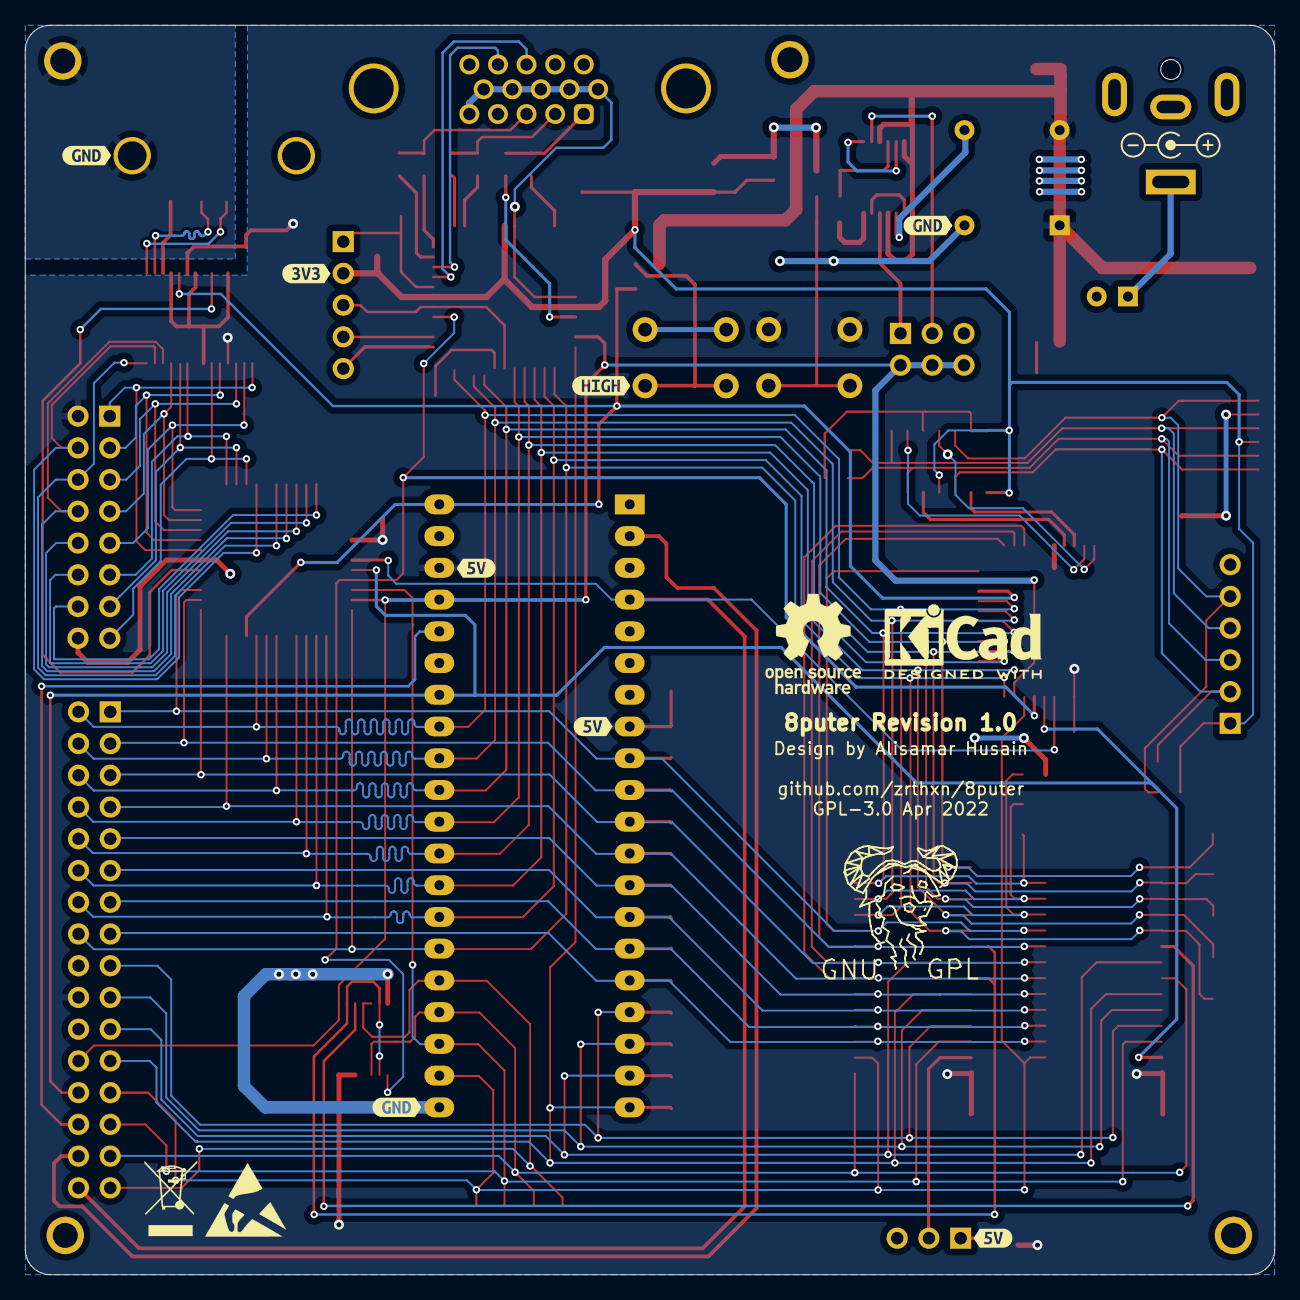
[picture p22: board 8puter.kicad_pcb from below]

Board: 2 copper layers, 100.0 x 100.0 mm, 99 parts (8 on the bottom side), 89 nets.

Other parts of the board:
kibuzzard-628B4C0E, kibuzzard-628B4C0E#2, kibuzzard-628B4C0E#3: G***; kibuzzard-628B4C0E
kibuzzard-628B4D67: G***; kibuzzard-628B4D67
kibuzzard-628B4DA2: G***; kibuzzard-628B4DA2
kibuzzard-628B4EC0: G***; kibuzzard-628B4EC0
kibuzzard-628B4F23: G***; kibuzzard-628B4F23
kibuzzard-628B4F43: G***; kibuzzard-628B4F43
kibuzzard-628B4F86, kibuzzard-628B4F86#2: G***; kibuzzard-628B4F86
kibuzzard-628B50D2: G***; kibuzzard-628B50D2
kibuzzard-628B5292: G***; kibuzzard-628B5292

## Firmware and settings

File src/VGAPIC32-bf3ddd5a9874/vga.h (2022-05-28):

#ifndef __VGA_H__
#define __VGA_H__

#define LINE_LENGTH	160				/* pixels */
#define LINE_COUNT	256				/* distinct display lines */

#define HFREQ_LIMIT	643				/* 24MHz cycles */
#define HSYNC_START	460				/* 24MHz cycles */
#define HSYNC_LIMIT	64				/* 24MHz cycles */
#define HSYNC_END	(HSYNC_START + HSYNC_LIMIT)

#define VISIBLE_START	70				/* horizontal lines, back porch end */
#define VFP_START	(VISIBLE_START + 2 * LINE_COUNT)
#define VSYNC_START	620				/* horizontal lines, front porch end */
#define VSYNC_END	622				/* horizontal lines, back porch start */

#define SCREEN_BASE	256
#define SCREEN_SIZE	(40 * 1024)
#define SCREEN_LIMIT	(SCREEN_BASE + SCREEN_SIZE)

#define SCREEN_BASE_KSEG0	(KSEG0_BASE + SCREEN_BASE)
#define SCREEN_LIMIT_KSEG0	(KSEG0_BASE + SCREEN_LIMIT)

#define IRQ_STACK_LIMIT		SCREEN_BASE_KSEG0
#define IRQ_STACK_TOP		(IRQ_STACK_LIMIT - 64)

#endif /* __VGA_H__ */

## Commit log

2022-04-05 Basic schematic
    [8puter.kicad_pcb, 8puter.kicad_sch, memory.kicad_sch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]
2022-04-05 Memory Module
    [8puter.kicad_pcb, 8puter.kicad_sch, memory.kicad_sch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]
2022-04-07 Bus control
    [8puter.kicad_pcb, 8puter.kicad_sch, decoder.kicad_sch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]
2022-04-09 New address decoder
    [8puter.kicad_pcb, 8puter.kicad_sch, buses.kicad_sch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]
2022-04-09 todo clock
    [clock.kicad_sch]
2022-04-10 Board layout, addr bus
    [8puter.csv, 8puter.kicad_pcb, 8puter.kicad_sch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]
2022-04-11 More routing, USB iface
    [8puter.kicad_pcb, 8puter.kicad_sch, buses.kicad_sch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]
2022-04-14 Pivot to 6502
    [8puter-B_Cu.gbr, 8puter-B_Mask.gbr, 8puter-B_Paste.gbr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]
2022-04-19 Serial interface
    [8puter.kicad_pcb, 8puter.kicad_sch, clock.kicad_sch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]
2022-04-20 Serial, debug and prph headers
    [8puter.kicad_pcb, 8puter.kicad_sch, clock.kicad_sch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]
2022-04-20 Pulldowns, minor reroute
    [8puter.csv, 8puter.kicad_pcb, 8puter.kicad_sch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]
2022-04-21 First completed routing
    [8puter.kicad_pcb, 8puter.kicad_sch, clock.kicad_sch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]
2022-04-21 Gerber Plots
    [8puter-B_Cu.gbr, 8puter-B_Mask.gbr, 8puter-B_Paste.gbr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]
2022-04-22 board improvements
    [8puter-B_Cu.gbr, 8puter-B_Mask.gbr, 8puter-B_Paste.gbr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]
2022-04-22 some docs
    [8puter-B_Cu.gbr, 8puter-B_Mask.gbr, 8puter-B_Paste.gbr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]
2022-04-23 update schematic
    [8puter-B_Cu.gbr, 8puter-B_Mask.gbr, 8puter-B_Paste.gbr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]
2022-04-24 serial rollback
    [8puter.kicad_pcb, 8puter.kicad_sch, memory.kicad_sch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]
2022-04-27 fix peripherals, add SPI
    [8puter-B_Cu.gbr, 8puter-B_Mask.gbr, 8puter-B_Paste.gbr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]
2022-04-27 Cleanup board
    [8puter-B_Cu.gbr, 8puter-B_Mask.gbr, 8puter-B_Paste.gbr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]
2022-04-27 Zipup gerbers
2022-04-29 Gerber format
    [8puter-B_Cu.gbl, 8puter-B_Cu.gbr, 8puter-B_Mask.gbr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]
2022-04-29 Huge mistake CPU fp
    [8puter-B_Cu.gbl, 8puter-B_Mask.gbs, 8puter-B_Paste.gbp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]
2022-04-29 images, plots
    [8puter-B_Cu.gbl, 8puter-B_Mask.gbs, 8puter-B_Paste.gbp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]
2022-04-29 bigger header pins
    [8puter-B_Cu.gbl, 8puter-B_Mask.gbs, 8puter-B_Paste.gbp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]
2022-05-02 small updates
    [8puter-B_Cu.gbl, 8puter-B_Mask.gbs, 8puter-B_Paste.gbp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]
2022-05-03 better file structure
    [8puter.csv, 8puter.kicad_pcb, storage.kicad_sch]
2022-05-11 Comments in Sch
    [8puter.kicad_pcb, 8puter.kicad_sch, clock.kicad_sch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]
2022-05-22 nicer label
    [8puter.kicad_pcb, video.kicad_sch]
2022-05-23 improve routing
    [8puter.csv, 8puter.kicad_pcb, memory.kicad_sch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]
2022-05-23 improve schematic
    [8puter.kicad_sch, memory.kicad_sch]
2023-07-11 KiCad v7
    [8puter-B_Cu.gbl, 8puter-B_Mask.gbs, 8puter-B_Paste.gbp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]
2023-08-01 Updated gerbers zip
2023-08-20 Board Revision
    [8puter-B_Cu.gbl, 8puter-B_Mask.gbs, 8puter-B_Paste.gbp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]

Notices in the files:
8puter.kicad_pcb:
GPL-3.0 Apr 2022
